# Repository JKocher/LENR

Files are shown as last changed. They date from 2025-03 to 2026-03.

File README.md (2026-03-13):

# Open-Source Sonoluminescence LENR Reactor

Welcome to the open-source LENR reactor project—a public effort to explore the possibility of designing and developing an intrinsically safe Low Energy Sonoluminescence Reactor with **no radioactive materials** involved.

This project provides a **starting point for researchers and engineers** interested in low energy nuclear reactions (LENR), sonoluminescence, and cavitation-based energy systems.

## What’s Inside

This repository contains (or will eventually contain):

- **3D CAD Models** – A spherical reactor core design with hemispherical aluminum horns and water chamber.
- **Materials & Colloid Recipes** – Starting concentrations for nickel powder, neutron moderators, and optional gain media.
- **Bill of Materials (BOM)** – Components for building your own test reactor.
- **FEA Simulations** – Helmholtz equation acoustic modeling using Elmer FEM to analyze pressure wave behavior in the reactor cavity.
- **Python Utilities** – Scripts for basic simulation, data logging, and future control loop automation.
- **Sensor Placement and Strategy** – Photodiode-based Bremsstrahlung detection setup and flow diagram.
- **Experimental Protocols** – Concepts for safe and reproducible LENR experimentation.

## Project Goals

- Build a **low-cost, modular sonoluminescence reactor** that supports LENR experimentation.
- Enable community collaboration with **open-source hardware and software**.
- Establish **prior art and reproducibility benchmarks** for LENR systems.
- Provide a **data-driven experimental framework** focused on detecting anomalous heating, not rare nuclear events.

## Documentation

Refer to:

- [`Open-Source Sonoluminescence LENR Reactor v0.1.0.pdf`](./Open-Source%20Sonoluminescence%20LENR%20Reactor%20v0.1.0.pdf)
- [`Reactor Simulation Guide v0.1.0.pdf`](./Reactor%20Simulation%20Guide%20v0.1.0.pdf)
- [`Sonoluminescence Reactor System Diagram v0.1.0.pdf`](./Sonoluminescence%20Reactor%20System%20Diagram%20v0.1.0.pdf)

These include detailed system architecture, simulation workflow, design philosophy, core scientific rationale, and practical insights for reproducible LENR research.

For acoustic simulation results and analysis, see [`docs/`](./docs/) — includes FEM/analytical comparison, cavity mode predictions, and a printable PDF report.

## License

This project is licensed under the [MIT License](./LICENSE). You are free to use, modify, and build upon it—ideally for the benefit of science and humanity.

## Feedback & Contributions

Questions, improvements, and experimental results are welcome. Please reach out via email:

info@aquaco2.com  
Join the movement: Let’s build a reproducible, accessible LENR platform together.

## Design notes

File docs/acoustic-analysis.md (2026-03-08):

# Acoustic Analysis: Frequency Sweep Post-Processing & Cavity Mode Predictions

## Overview

This document summarizes analysis performed on the LENR reactor's acoustic simulation using two new tools: `sweep_analysis.py` (FEM post-processor) and `cavity_modes.py` (analytical mode calculator). During validation of these tools, we identified two unit-consistency issues in the upstream simulation that were preventing standing wave formation.

## New Tools

### `Elmer-3a/sweep_analysis.py`

Post-processes VTU files from `frequency_sweep.py`. Extracts the complex pressure amplitude from Elmer's Helmholtz solver output (two DOFs: real and imaginary parts) and computes diagnostics for each frequency.

**Outputs:**
- Frequency response plot (max/mean pressure on log scale, center pressure on linear scale)
- Axial pressure profiles (horn-to-horn, all frequencies overlaid)
- Enriched CSV with per-frequency metrics: max pressure, mean pressure, center pressure, max pressure location

**Usage:**
```bash
cd Elmer-3a
python sweep_analysis.py                    # default: reads sweep_results/
python sweep_analysis.py path/to/results    # custom directory
```

**Dependency:** `meshio` (`pip install meshio`) for reading VTU files.

### `Simple Python Sim/cavity_modes.py`

Analytical acoustic mode calculator using spherical Bessel functions. Computes resonant frequencies for a spherical water-filled cavity under two idealized boundary conditions:

- **Pressure-release** (p=0 at wall): zeros of j_n(ka) — lower frequency bound
- **Rigid wall** (dp/dr=0 at wall): zeros of j_n'(ka) — upper frequency bound

The real aluminum-water interface (impedance ratio ~9) lies between these limits.

**Features:**
- Mode table for any cavity radius
- Reverse design: target frequency → optimal radius
- Radial mode shape profiles
- Design chart: frequency vs cavity size with transducer matching

**Usage:**
```bash
cd "Simple Python Sim"
python cavity_modes.py                      # default: a=18.517mm, c=1497 m/s
python cavity_modes.py --freq 40            # optimal radius for 40 kHz
python cavity_modes.py --plot               # generate mode shape plots
python cavity_modes.py --sweep 20 120 1     # analytical frequency sweep
```

---

## Findings: Unit Consistency Issues

While validating the analysis tools against the FEM results, we traced the absence of standing waves in the simulation to two root causes.

### Issue 1: Sound Speed Units in `case.sif`

The Elmer mesh is defined in **millimeters** (coordinates range from 0–50 mm). However, the material properties in `case.sif` use SI units:

| Property | Value in case.sif | Unit | Consistent with mm mesh? |
|---|---|---|---|
| Sound Speed (water) | 1497.0 | m/s | No — should be mm/s |
| Sound Speed (aluminium) | 5000.0 | m/s | No — should be mm/s |
| Density (water) | 998.3 | kg/m³ | No — should be tonne/mm³ |
| Density (aluminium) | 2700.0 | kg/m³ | No — should be tonne/mm³ |

**Impact:** The Helmholtz equation computes wavenumber k = ω/c. With c = 1497 m/s and ω for 40 kHz:

```
k = 2π × 40000 / 1497 = 167.8 /m = 0.168 /mm
λ = 2π/k = 37.4 mm     ← what the solver SHOULD compute
```

But the mesh is in mm, so the solver interprets c = 1497 as 1497 mm/s:

```
k = 2π × 40000 / 1497 = 167.8 /mm
λ = 2π/k = 0.037 mm    ← what the solver ACTUALLY computes
```

The wavelength (0.037 mm) is **400× smaller** than the mesh element size (~1.5 mm). The mesh cannot resolve these waves, so the solver produces a Laplace-like solution with no wave physics — explaining the simulation guide note: *"Suspect there are still simulation issues, since we are not achieving a standing wave."*

**Corrected values (mm-tonne-s unit system):**

| Property | Corrected Value | Unit |
|---|---|---|
| Sound Speed (water) | 1,497,000.0 | mm/s |
| Sound Speed (aluminium) | 5,000,000.0 | mm/s |
| Density (water) | 9.983e-10 | tonne/mm³ |
| Density (aluminium) | 2.7e-9 | tonne/mm³ |

### Issue 2: Diameter/Radius in the Python Simulation

The analytical Python simulation (`Hemisphere Simulations Numpy Max PDelta.txt`) uses:

```python
radius_sphere = 37e-3   # 37 mm
```

The actual cavity radius from the CAD geometry is **18.517 mm**. The value 37 mm is the **diameter** (2 × 18.517 ≈ 37.034). This causes the Python simulation to model a cavity with 8× the volume of the actual reactor, producing incorrect resonance predictions and pressure distributions.

Evidence: historical plot filenames in the repository contain `r18.517`, confirming the intended radius.

---

## Validation: Before and After

### Pressure Field at 40 kHz

With original units, the pressure field shows energy trapped in the aluminum horns with no penetration into the water cavity. Center pressure is ~10⁻²¹ (numerical zero). With corrected units, wave patterns form across the full geometry.

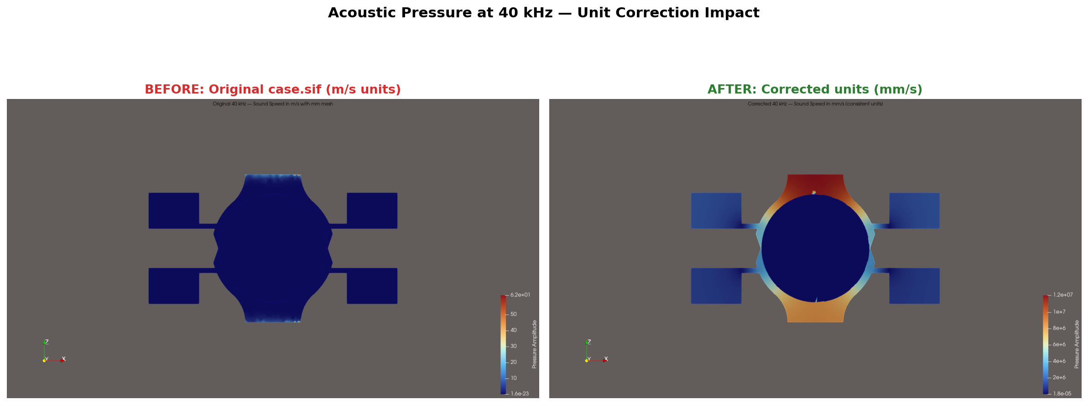
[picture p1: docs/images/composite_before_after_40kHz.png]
Before vs After at 40 kHz


### Frequency Response

The original sweep (20–110 kHz) shows monotonic 1/f decay — no resonance at any frequency. The corrected sweep reveals clear resonance structure:

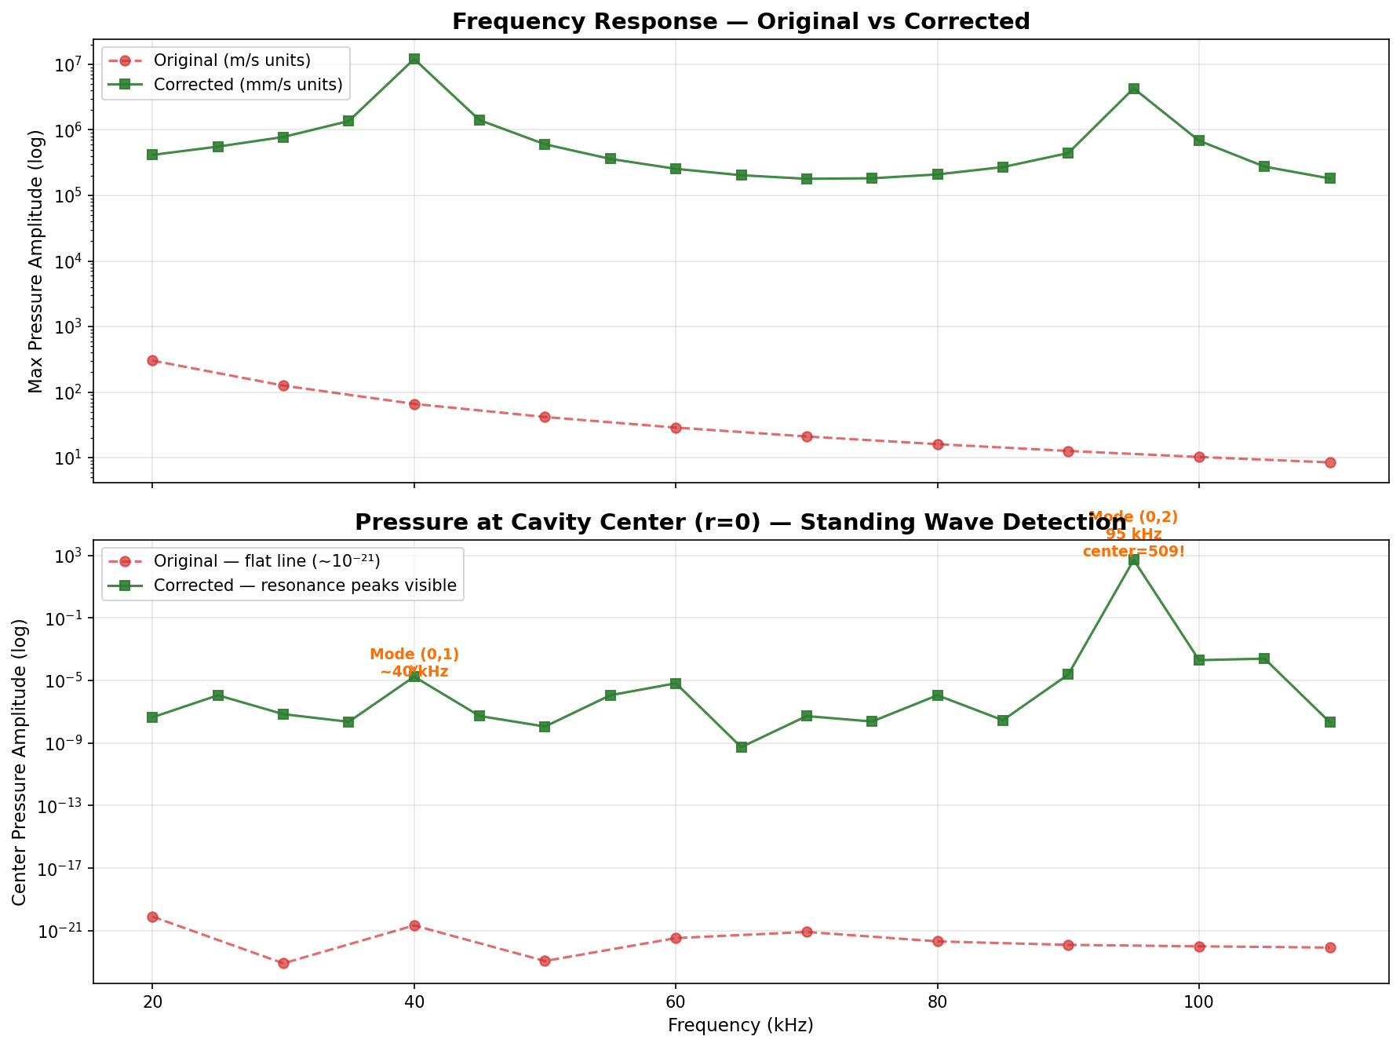
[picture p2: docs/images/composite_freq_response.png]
Frequency Response Comparison


**Key findings:**
- **Mode (0,1) at ~40 kHz** — center pressure rises to 1.75×10⁻⁵ (modest, first breathing mode)
- **Mode (0,2) at 95 kHz** — center pressure = **509** (massive resonance, 5 orders of magnitude above background)

### FEM vs Analytical Predictions

Both the FEM results and the analytical Bessel function predictions agree on the resonance locations:

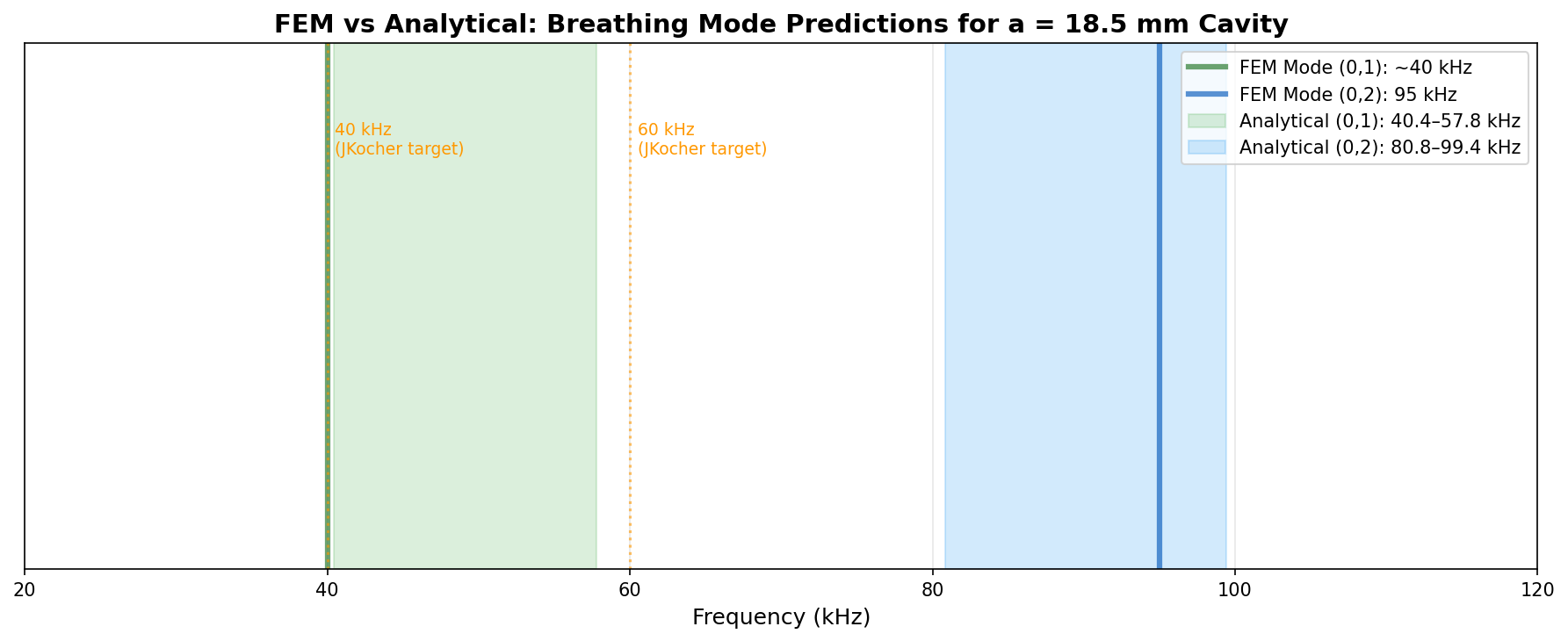
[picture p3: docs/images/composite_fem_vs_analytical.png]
FEM vs Analytical


| Mode | Analytical Range | FEM Peak | Match? |
|---|---|---|---|
| (0,1) | 40.4 – 57.8 kHz | ~40 kHz | Yes — at the pressure-release limit |
| (0,2) | 80.8 – 99.4 kHz | 95 kHz | Yes — within the predicted band |

### 95 kHz Resonance: Pressure and Temperature

At the (0,2) breathing mode, acoustic energy focuses at the cavity center. Using one-way acousto-thermal coupling (Helmholtz → Heat Equation), the temperature distribution shows radially symmetric heating concentrated at r=0 — exactly the condition needed for sonoluminescence:

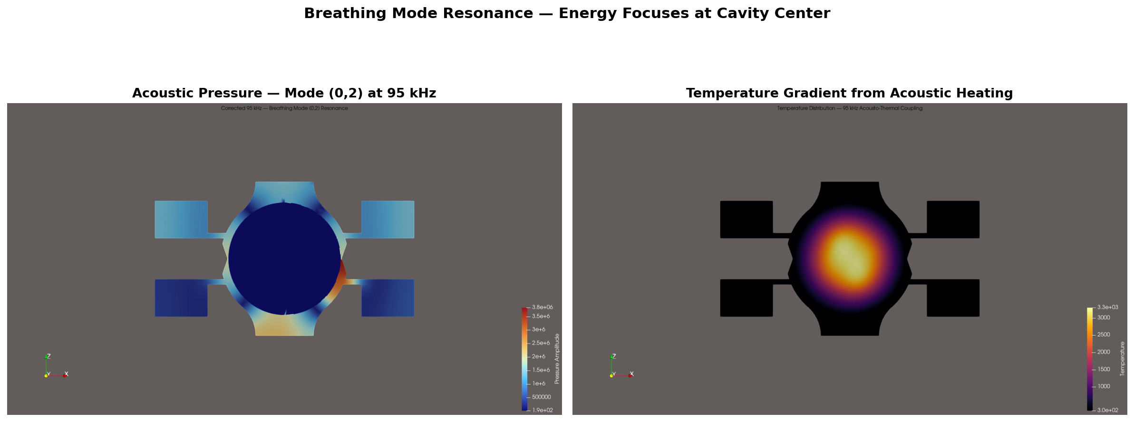
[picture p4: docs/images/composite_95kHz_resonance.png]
95 kHz Resonance


### Cavity Design Chart

The analytical tool generates design charts showing how the fundamental breathing mode frequency varies with cavity radius. This enables rapid evaluation of different cavity sizes without running the full FEM solver:

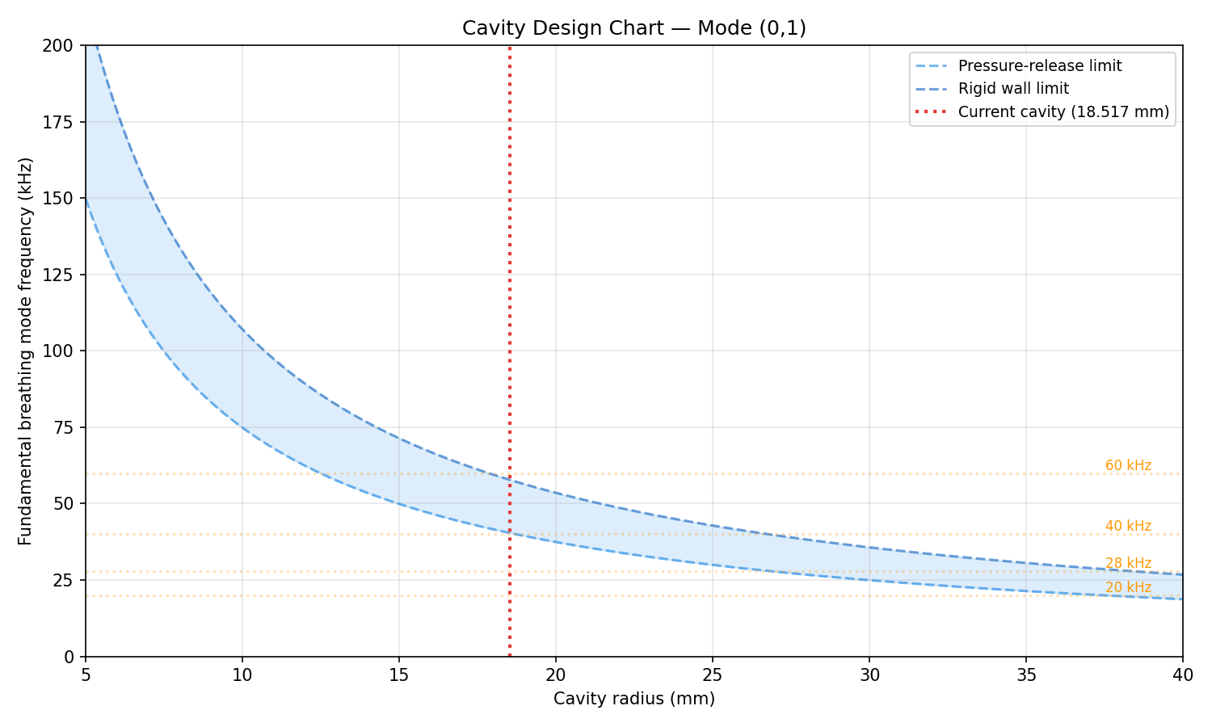
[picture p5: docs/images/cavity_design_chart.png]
Cavity Design Chart


### Breathing Mode Shapes

Radial pressure profiles for the first three breathing modes under both boundary conditions, plus the analytical frequency response showing the resonance peak:

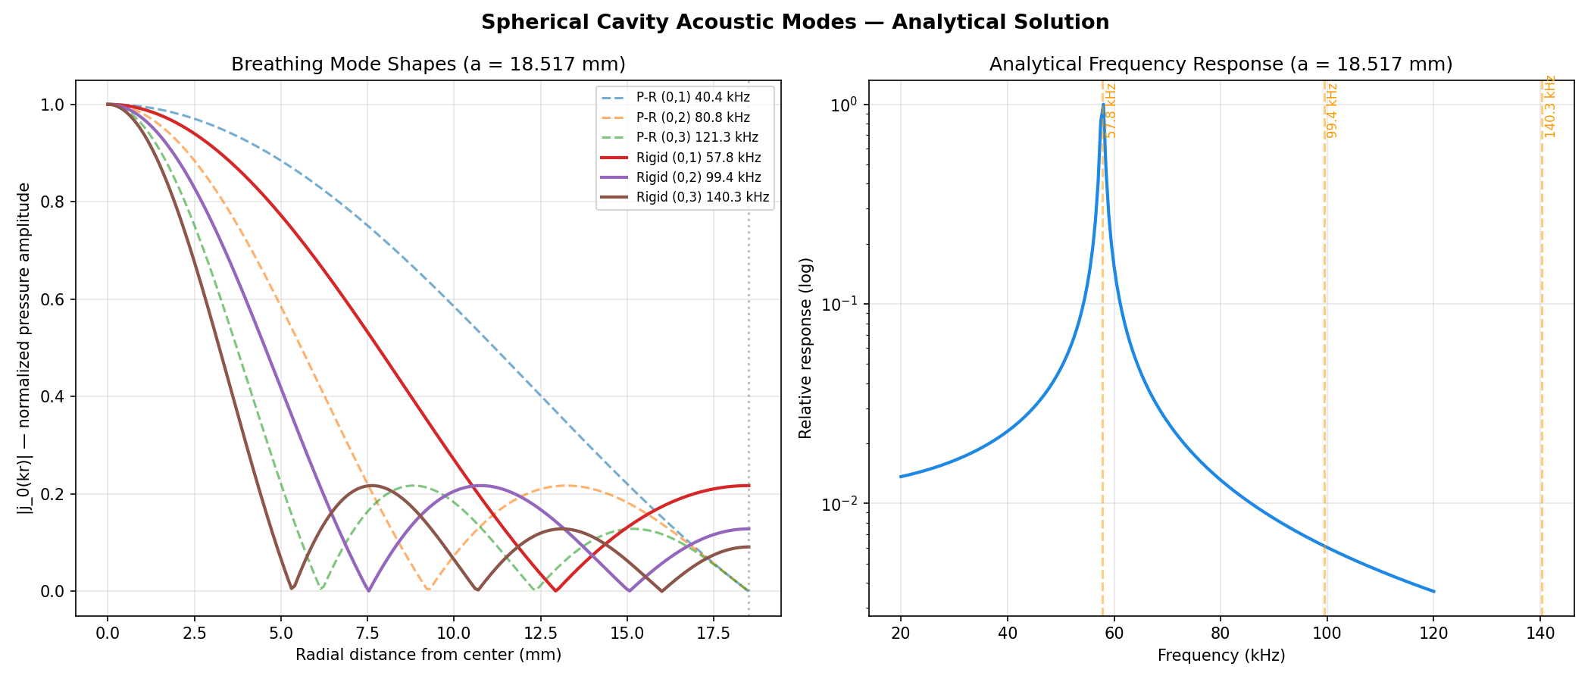
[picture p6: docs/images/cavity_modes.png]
Cavity Modes


---

## Recommendations

1. **Update `case.sif` material properties** to use mm-consistent units (mm/s for sound speed, tonne/mm³ for density). Only the Helmholtz-relevant properties need correction — thermal and electromagnetic properties are not used by the current solver.

2. **Target 95 kHz** for maximum center pressure amplification. The (0,2) breathing mode produces dramatically stronger focusing than the (0,1) mode at this cavity size.

3. **Fix `radius_sphere`** in the Python simulation to 18.517e-3 (radius, not diameter).

4. **Use `cavity_modes.py`** for rapid parametric studies before running full FEM sweeps. The analytical predictions bracket the FEM results reliably.

---

## Data Summary

All corrected simulation data is available in `Elmer-3a/sweep_results/`:

| File | Description |
|---|---|
| `full_sweep_fixed.csv` | Corrected sweep, 20–90 kHz (5 kHz steps) |
| `fine_sweep_58khz.csv` | Fine sweep, 55–62 kHz (0.25 kHz steps) |
| `high_freq_fixed.csv` | High frequency extension, 95–110 kHz |
| `damping_study_58khz.csv` | Damping sensitivity at 58 kHz |

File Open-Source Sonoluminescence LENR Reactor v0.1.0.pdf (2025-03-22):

# LENR: Toward a Small Form Factor Sonoluminescence Reactor

JASON KOCHER, Author
2025

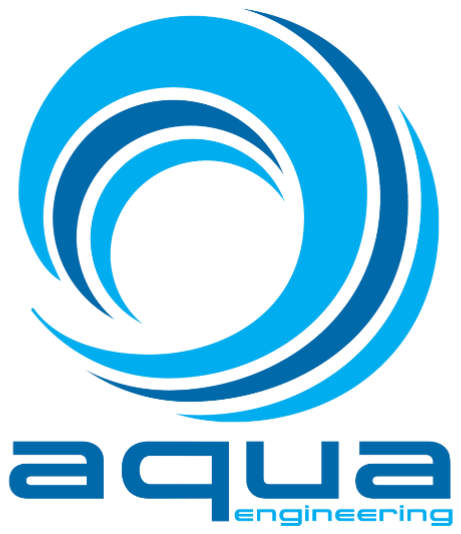
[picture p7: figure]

© 2025 Jason Kocher, Aqua Engineering, LLC This work is licensed under the MIT License. See LICENSE.txt for full terms. Open-source disclosure in the public interest. Contact: info@aquaco2.com

Design History:
3/22/25 – v0.1.0, Initial Draft

## Contents

## ABSTRACT

For decades, anomalous heating has been observed in metals such as Nickel and Palladium when in the presence of Hydrogen or Deuterium. The field of LENR has been highly controversial and thus far has had difficulty delivering reproducible, verifiable data. As a result, we do not yet see LENR reactors in commercial use.

This project aims to create a modular, low-cost, open-source experimental ecosystem. Key parallel development areas include:

- **Sonoluminescence Reactor Core**
- Focus of this paper
- Intrinsic safety (no chain reactions)
- **Reactant Refresh & Control Loop**
- Control temp/pressure
- Recirculate & refresh materials
- Safety valves, burst protection
- **External Heat Exchanger Loop**
- Isolate reactor from power generation side
- **Power Generation**
- DC/AC via permanent magnet generator
- Ability to array multiple modules
- **Commercialization Considerations**
- Modularity
- Cost effectiveness
- IP strategy — establish prior art

## INTRODUCTION

Based on the assumption that anomalous heating in LENR systems is in fact caused by fusion events involving reactions of nickel or palladium with hydrogen or deuterium, we will proceed experimentally with a prototype sonoluminescence fusion reactor. The features of this reactor are based on various proven background technologies including water carbonation, ultrasonic cleaning, and hydrogen production via electrolysis.

## CAVITATION AND SONOLUMINESCENCE

To achieve a high pressure, high temperature reaction site, we will use the predicate phenomenon of sonoluminescence. When a sufficiently energetic cavitation bubble collapses in water, light will be emitted due to the extremely high temperature and pressure created momentarily. The temperature of this collapsing zone has been estimated to exceed tens of thousands of Kelvin and exhibit extreme pressures. While this temperature is well below that required for classical fusion, it may be sufficient for initiating reactions between hydrogen-loaded nickel under localized and non-classical conditions.

## Ultrasonic Horn Configuration

To meet our cost requirements and with the goal of simple reproducibility, we’ll use a commodity 60W ultrasonic cleaner Piezo module.

The reactor will have two horns arranged in a hemisphere, the exact shape of which will evolve as the project evolves. Initial goals are to start with the following:
- 40 KHz module
- 60W rated
- Tune experimentally by sweeping frequency and power until maximum Bremsstrahlung output from the viewport of the reactor. This will avoid missing the mark of maximum target power that could be a pitfall of other methods of tuning. Essentially we will close the acoustic loop at visual output of cavitation and store these characteristic variables in code.

## Water Volume (Bulk Medium)

To facilitate the reaction, H2O or D2O will be used. D2O may emit a neutron, while H20 may emit a gamma ray for each nuclear fusion event. Regardless of the bulk medium, we will add neutron moderation as a primary safety measure.

Neutron Moderator:
- Boric Acid
- Gadolinium III Oxide

Once we have a primary safety shield for neutrons and have gathered baseline temperature data, we can look to improve the hot spot by interpreting values at the Bremsstrahlung sensor.

Hot Spot Enhancers:
- Lithium Chloride (solute)
- Beryllium Oxide (colloid)

## Nickel Target

To meet the goals of a low-cost reactant, nickel colloidal powder has been identified as the primary fusion reactant and target. (It should be noted that in many cases finding nickel powder in experimental quantities is more costly than sourcing small amounts of palladium powder. As a result, it is suggested to also run palladium experiments for research purposes. The assumption is that once this technology is commercialized on a large scale, nickel powder will be commoditized to a much lower price than palladium). It will be important to experimentally identify various optimizations within nickel powder variants:

Nickel Powder Variants:
- Spherical
- Need to understand acoustic clumping
- Flake
- Possibly more nucleation sites and fissures available for hydrogen loading
- Need to understand acoustic clumping
- Sizing
- 1-500nm – May be more prone to complete oxidation
- 500nm-10um – May survive complete oxidation
- Over 10um – May not stay in colloidal suspension long enough between fluff cycles ¹
- NiTi
- Nickel-Titanium may survive oxidation better and provide increased hydrogen loading
- May have shape memory alloy effects that create better confinement of loaded hydrogen or deuterium.
- Ni + Pd and/or Lanthanides
- Possibly use a very small amount of Pd to kick off Ni fusion events

- Lanthanides (Lanthanum Nickel for hydrogen storage may help contribute and/or confine hydrogen or deuterium during sonoluminescence).

Nickel Wire:
- Wire can be used as the electrolysis site for Hydrogen gas creation and possible simultaneous loading of Hydrogen into the Nickel.
- Wire can be sealed against, so we can store a spool in a separate Hydrogen chamber with no water.
- Wire can be continuously pulled and spooled, providing a sample that can be marked in time and corroborated with control box test data.
- Size of the wire can be precisely controlled.
- Position of the wire can be precisely controlled with a micrometer adjustment stage or CNC module.
- Wire can be heated by adding more electrical energy.
- Possible application of the Lorentz force, perhaps used to crush the Nickel wire inward, in phase with the acoustic cavitation. Higher voltage would be briefly applied to induce this force. May also keep a DC voltage offset to allow continuous production of Hydrogen or Deuterium at the wire surface (electrolysis).

## Bremsstrahlung Sensor

To close the loop of the acoustics, water pressure, and temperature variables, we’ll ultimately want to look at the cavitation point and its resulting brightness. This radiation is assumed to be Bremsstrahlung and visible light, thus it can be monitored with a photodiode in keeping with the goals of simplicity and low cost. Photomultipliers and neutron detectors are assumed to be cost prohibitive for this ecosystem, though experiments with such devices are encouraged.

## Pumped-Laser Bremsstrahlung Detector & Target Booster (Optional)

An optional method for hot spot enhancement or simply to have a better Bremsstrahlung sensor may be to create a laser cavity between two sight ports of the reactor, essentially creating an internal dye laser. Two gain mediums are proposed, depending on which end of the electromagnetic spectrum we wish to experiment with:

460 nm Blue Light:
- Coumarin 102, 330-420nm Absorption
- Note: Must operate under 150C to avoid breakdown of dye

1064 nm Infrared Light:
- Neodymium Colloid, 740-810nm Absorption

Should the cavity reflectors be focused at the central point, it’s possible that the added laser energy may act to stabilize the bubble position and increase the heating of the target zone by consolidating electromagnetic radiation that would otherwise be lost to bulk heating. Otherwise, an incomplete focal point or parallel-mirror design might still show utility as a sensor without heating effects at the target.

Possible Dye Laser Uses:
- Sensing Bremsstrahlung intensity
- Detecting bubble position and quality
- Detecting and closing loop on bubble frequency
- Target heating and bubble stabilization through higher temp non-contact nucleation site.

## System Diagram

The following system diagram serves as the starting point for ideation. It is expected that this project will evolve rapidly, so the details will change.
See “Sonoluminescence Reactor vx.x.x.PDF”

## Argon Sparger

To provide a controlled process pressure, argon will be injected and regulated on the output at a head gas location above the reactor’s liquid loop. Dissolved argon may help modify the sonoluminescence intensity and bubble size.

## Data Collection Strategy

Each run should log:

- Input parameters (frequency, voltage, colloid recipe and concentration, etc.)
- Measured temperature rise over time
- Bremsstrahlung intensity
- Reactor vessel pressure

All data should be saved in CSV format for processing using Python code.

## Bill of Materials

The bill of materials will be updated periodically and added to this project repository.

## FINAL CONCLUSION

## Core Insight

High-energy emissions from sonoluminescence are brief, local, and dissipate rapidly in fluid mediums, making classical detection methods ineffective. Detection must instead be reframed around reproducible, aggregate thermal behavior under tightly defined control conditions:
- The flash volume is on the order of microns, and the duration is picoseconds to nanoseconds.
- Any X-rays, UV, or neutrons emitted will follow the inverse-square law in free space (Intensity is inversely proportional to 1/ radius squared). In our case, it’s not free space, it’s a chaotic, dense, hot fluid medium which absorbs, scatters, and damps signals.
- Net result – Most of the high-energy output is thermalized immediately, so detection beyond the medium becomes nearly impossible without massive event rates. We need the data to guide us down the path of increasing event rates while the system is buried below the detectable signal to noise ratio. (Likely a reason many prior LENR experiments have failed.)

## Why do other LENR experiments fail?

Hypothesis - Most LENR/SL experiments fail to detect anything because signal-to-noise is impossibly small, and detection strategy assumes classical nuclear event behavior.

Detectors looking for MeV neutrons or hard X-rays may miss soft X-rays, UV, low-energy betas, heat, or phonon interactions.

## Core Insight & Philosophical Take

Take a data-driven, unbiased approach that tests hypotheses through null-hypothesis proofing and avoids theoretical tunnel vision.
Instead of asking “Did we see a neutron burst?”, we’re asking “Did the reactor heat up more than it should have, under strictly defined conditions, consistently?” If False, sweep new variables, if True, adjust and sweep the variables for optimization of heat output. Iterate this cycle until an empirically viable reactor design is created.

## References:

References have been intentionally omitted from this document to maintain a clean, empirically grounded engineering framework.
This work is focused on design, reproducibility, and experimentation, and is intended to serve as a practical launch point for LENR investigation through sonoluminescence.

## Notes

1. A “fluff cycle” is assumed to be a pulse of Argon or other agitation method that guarantees a periodic redistribution of the colloid.

## License:

This license applies to all files in this project, including 3D models, 2D CAD drawings, engineering documentation, source code, and any other associated files, unless otherwise noted.

MIT License

Copyright (c) 2025 Jason Kocher, Aqua Engineering, LLC

Permission is hereby granted, free of charge, to any person obtaining a copy of this software and associated documentation files (the "Software"), to deal in the Software without restriction, including without limitation the rights to use, copy, modify, merge, publish, distribute, sublicense, and/or sell copies of the Software, and to permit persons to whom the Software is furnished to do so, subject to the following conditions:

The above copyright notice and this permission notice shall be included in all copies or substantial portions of the Software.

THE SOFTWARE IS PROVIDED "AS IS", WITHOUT WARRANTY OF ANY KIND, EXPRESS OR IMPLIED, INCLUDING BUT NOT LIMITED TO THE WARRANTIES OF MERCHANTABILITY, FITNESS FOR A PARTICULAR PURPOSE AND NONINFRINGEMENT. IN NO EVENT SHALL THE AUTHORS OR COPYRIGHT HOLDERS BE LIABLE FOR ANY CLAIM, DAMAGES OR OTHER LIABILITY, WHETHER IN AN ACTION OF CONTRACT, TORT OR OTHERWISE, ARISING FROM, OUT OF OR IN CONNECTION WITH THE SOFTWARE OR THE USE OR OTHER DEALINGS IN THE SOFTWARE.

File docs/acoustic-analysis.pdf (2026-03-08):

LENR Reactor - Acoustic Analysis Report

# Acoustic Analysis Report

## LENR Sonoluminescence Reactor Frequency Sweep Post-Processing & Cavity Mode Predictions

Contributor: dbRollin
Repository: github.com/JKocher/LENR March 2026

## 1. Overview

This report documents analysis performed on the LENR reactor's acoustic simulation using two new tools: sweep_analysis.py (FEM post-processor) and cavity_modes.py (analytical mode calculator). During validation, two unit-consistency issues were identified that were preventing standing wave formation in the simulation.

The reactor is a spherical water-filled cavity (radius 18.517 mm) flanked by hemispherical aluminum acoustic horns, driven at ultrasonic frequencies to produce sonoluminescence. The simulation uses Elmer FEM to solve the Helmholtz equation for acoustic pressure wave propagation.

## 2. Finding: Sound Speed Unit Mismatch

The Elmer mesh is defined in millimeters, but the material properties in case.sif use SI units (m/s for sound speed, kg/m^3 for density). The Helmholtz equation computes wavenumber k = omega/c. With c = 1497 m/s interpreted as 1497 mm/s, the computed wavelength is 0.037 mm - 400x smaller than the mesh element size (~1.5 mm). The mesh cannot resolve these waves.

This explains the observation in the Simulation Guide: "Suspect there are still simulation issues, since we are not achieving a standing wave at either 40 kHz or 60 kHz."

Corrected values: Sound Speed = 1,497,000 mm/s (water), 5,000,000 mm/s (aluminium). Density = 9.983e-10 tonne/mm^3 (water), 2.7e-9 tonne/mm^3 (aluminium).

## 3. Finding: Diameter/Radius in Python Sim

The analytical Python simulation uses radius_sphere = 37e-3 (37 mm). The actual cavity radius from the CAD geometry is 18.517 mm. The value 37 mm is the diameter (2 x 18.517 ~ 37.034). This models a cavity with 8x the actual volume, producing incorrect resonance predictions. Historical plot filenames containing 'r18.517' confirm the intended radius.

## 4. Before & After: Pressure Field at 40 kHz

With original units, pressure is confined to the horn surfaces with zero penetration into the water cavity. With corrected units, wave patterns form across the full geometry.


Figure 1: Acoustic pressure at 40 kHz - original (left) vs corrected (right)

## 5. Frequency Response: Original vs Corrected

The original sweep shows monotonic 1/f decay with no resonance peaks. The corrected sweep reveals clear resonance structure with two breathing modes.


Figure 2: Max pressure (top) and center pressure (bottom) vs frequency

Key findings:
* Mode (0,1) at ~40 kHz: center pressure = 1.75x10-5 (first breathing mode) * Mode (0,2) at 95 kHz: center pressure = 509 (massive resonance)

## 6. FEM vs Analytical Validation

The analytical tool (cavity_modes.py) predicts resonance bands using spherical Bessel function zeros. The FEM results fall within the predicted bands for both modes, providing independent validation.


Figure 3: FEM peaks vs analytical prediction bands

Mode Comparison
Mode (0,1): Analytical 40.4 - 57.8 kHz, FEM ~40 kHz - at the pressure-release limit Mode (0,2): Analytical 80.8 - 99.4 kHz, FEM 95 kHz - within the predicted band

## 7. 95 kHz Resonance: Pressure & Temperature

At the (0,2) breathing mode, acoustic energy focuses at the cavity center. Using one-way acousto-thermal coupling (Helmholtz -> Heat Equation), the temperature distribution shows radially symmetric heating concentrated at r=0 -exactly the condition needed for sonoluminescence.

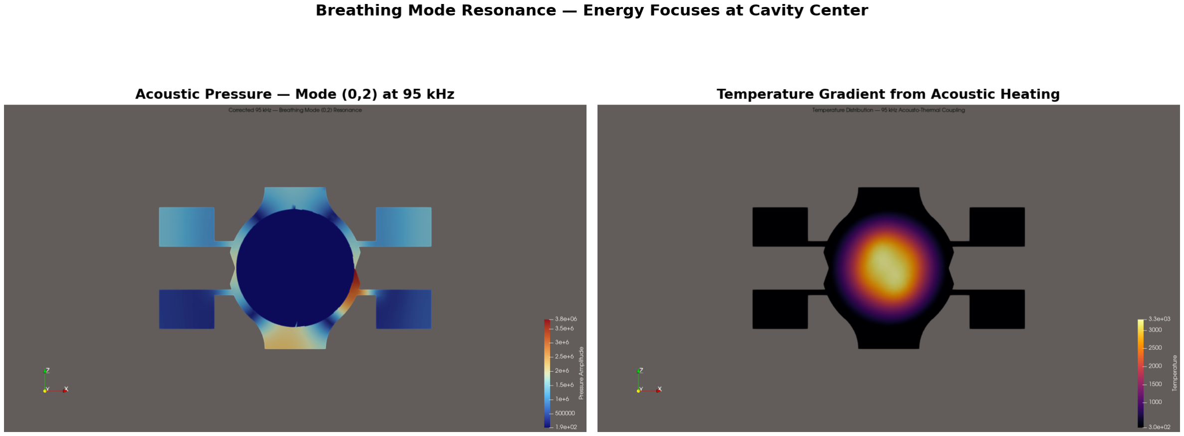
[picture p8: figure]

Figure 4: Acoustic pressure (left) and temperature gradient (right) at 95 kHz

## 8. Design Tools

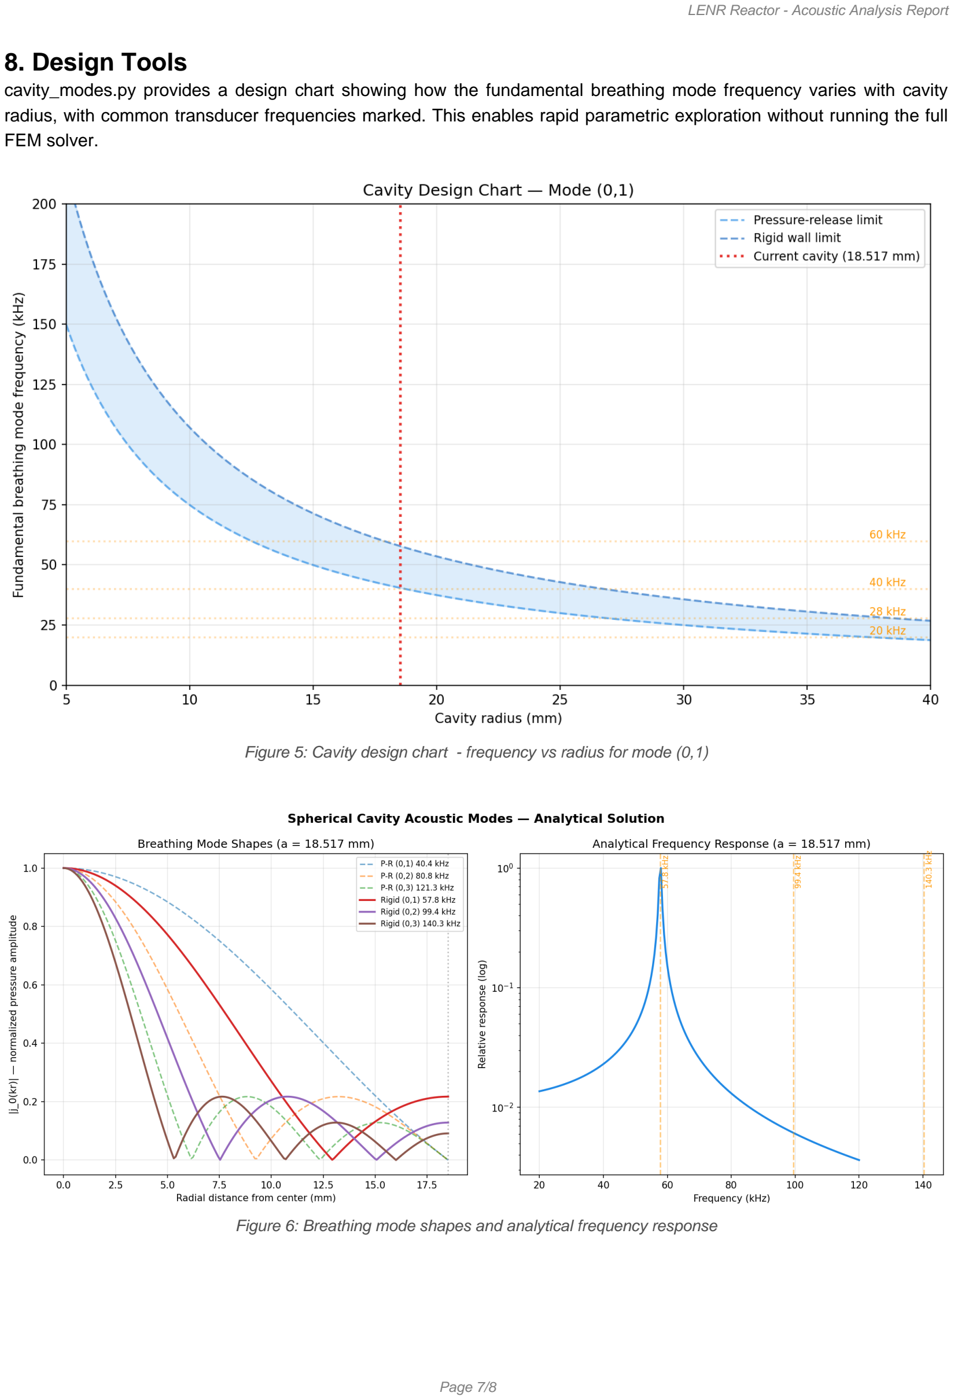
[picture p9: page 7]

cavity_modes.py provides a design chart showing how the fundamental breathing mode frequency varies with cavity radius, with common transducer frequencies marked. This enables rapid parametric exploration without running the full FEM solver.

Figure 5: Cavity design chart - frequency vs radius for mode (0,1)

Figure 6: Breathing mode shapes and analytical frequency response

## 9. Recommendations

1. Update case.sif material properties to use mm-consistent units. Only the Helmholtz-relevant properties need correction (sound speed and density). Thermal and electromagnetic properties are not used by the current solver.
2. Target 95 kHz for maximum center pressure amplification. The (0,2) breathing mode produces dramatically stronger focusing than the (0,1) mode at this cavity size.
3. Fix radius_sphere in the Python simulation to 18.517e-3 (radius, not diameter).
4. Use cavity_modes.py for rapid parametric studies before running full FEM sweeps. The analytical predictions bracket the FEM results reliably.

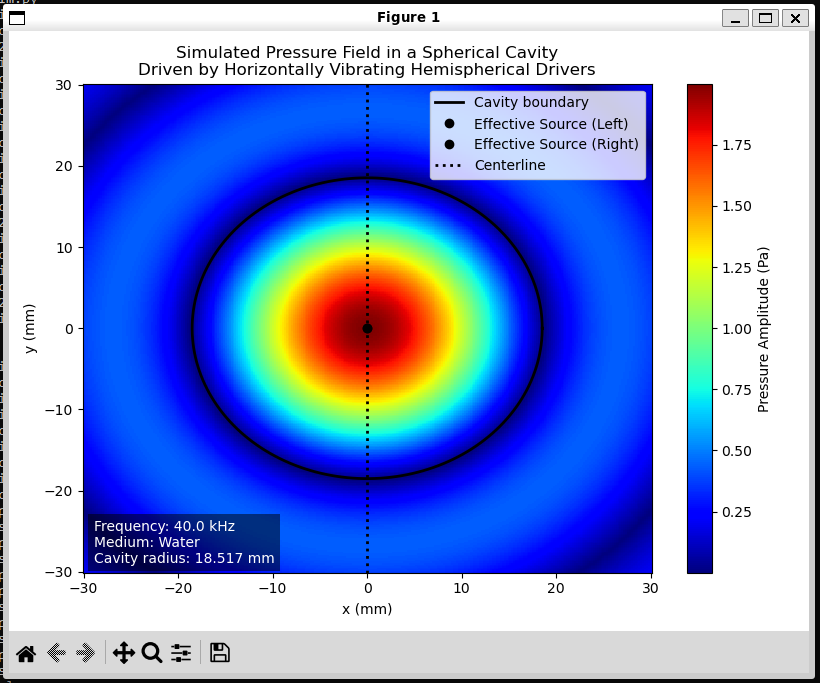
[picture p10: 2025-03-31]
Simple Python Sim/Acoustic Sim Python Plots/40kHz_r18.517mm.PNG

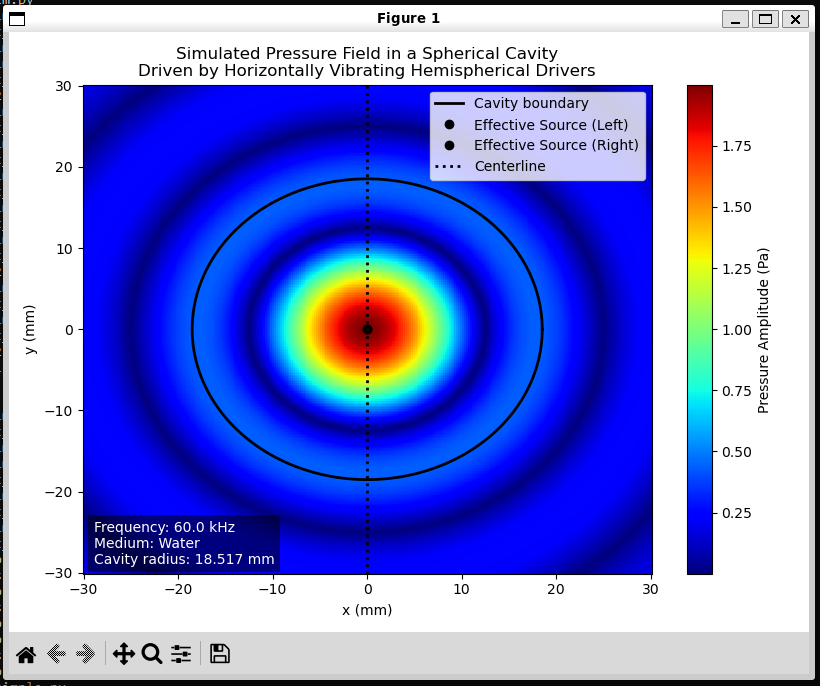
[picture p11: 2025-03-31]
Simple Python Sim/Acoustic Sim Python Plots/60kHz_r18.517mm.PNG

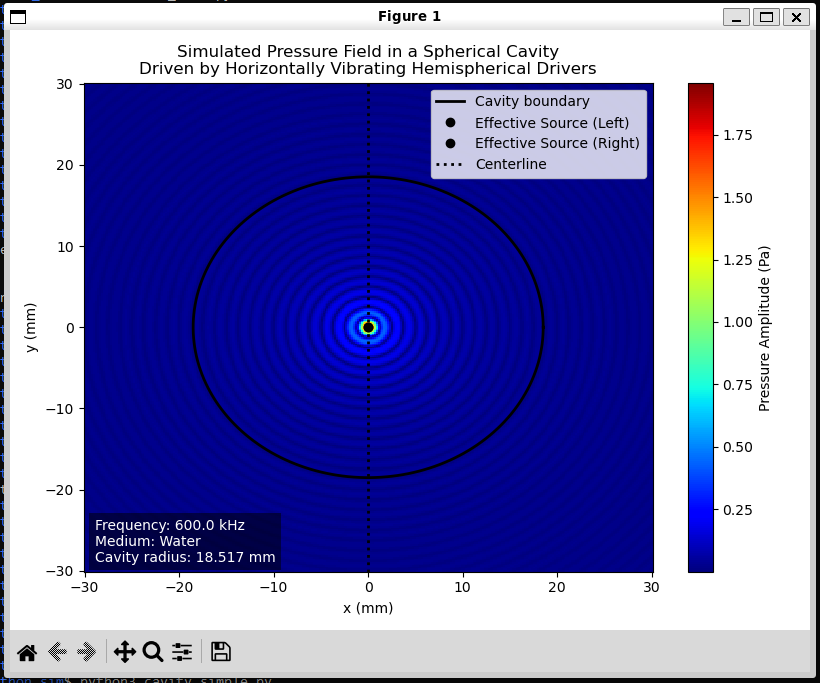
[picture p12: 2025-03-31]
Simple Python Sim/Acoustic Sim Python Plots/600kHz_r18.517mm.PNG

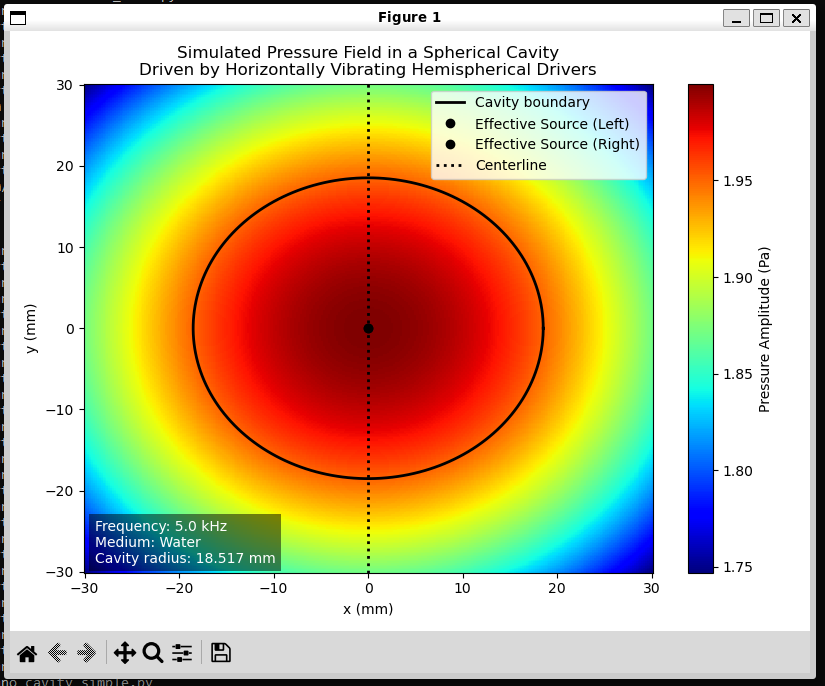
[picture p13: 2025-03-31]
Simple Python Sim/Acoustic Sim Python Plots/5kHz_r18.517.PNG

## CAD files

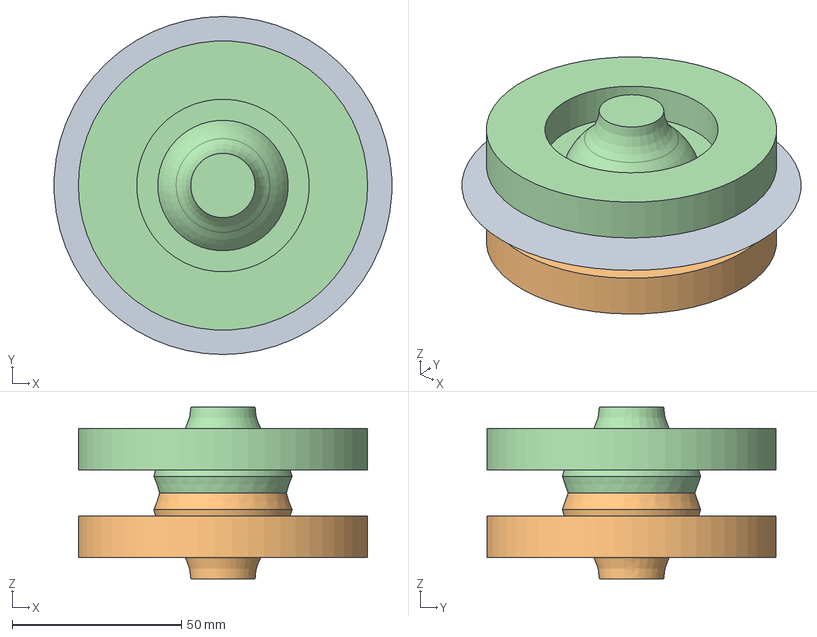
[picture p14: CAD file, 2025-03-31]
Elmer-3a/AQ25010-2002-Elmer-3.step
99.9 x 100.0 x 50.8 mm

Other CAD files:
Elmer-3a/AQ25010-2002-Elmer-3.stl

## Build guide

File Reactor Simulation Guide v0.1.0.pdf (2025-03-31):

# LENR: Toward a Small Form Factor Sonoluminescence Reactor

# FEA SIMULATION GUIDE


© 2025 Jason Kocher, Aqua Engineering, LLC This work is licensed under the MIT License. See LICENSE.txt for full terms. Open-source disclosure in the public interest. Contact: info@aquaco2.com

Design History:
3/31/25 – v0.1.0, Initial Draft – Suspect there are still simulation issues, since we are not achieving a standing wave at either 40kHz or 60kHz, and 60 should have an antinode (red area) in the middle. Higher frequencies attempted too with no visible standing wave in the bulk water sphere.

## Contents

## SCOPE

This working document details the methods necessary for accurate simulation of reactor horn geometries using open-source tools after the initial CAD generation. The workflow will be in order of operations:
CAD >> Gmsh (meshing) >> Elmer (Helmholtz FEA) >> ParaView (Visualization)
Process 1.1: Simulation order

## Downloads

This workflow was done on a Windows x64 PC. All downloads were for this OS.

## Gmsh:

https://gmsh.info/

## Elmer:

https://www.elmerfem.org/blog/binaries/https://sourceforge.net/projects/elmerfem/

## ParaView:

https://www.paraview.org/

## kHz to Radians Converter:

https://www.xconvert.com/unit-converter/kilohertz-to-radians-per-second/?measure=frequency&value=60 (https://www.xconvert.com/unit-converter/kilohertz-to-radians-per-second/?measure=frequency&value=60)

## 3D CAD MODEL

To have an accurate simulation, there are boundary conditions that must happen during the application of the Helmholtz equation. For example, the driven horn volume (aluminum) must touch the bulk media (water) without any gap in the mesh. To do this, we’ll need to develop a simplified geometrically accurate model of our reactor as one solid volume, split with surfaces designed to represent our boundaries. This can be done on the ‘surfaces’ workflow of Autodesk Fusion after the 3D solid has been created in the ‘solid’ workflow tab.

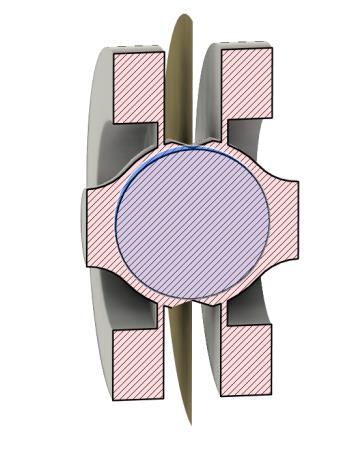
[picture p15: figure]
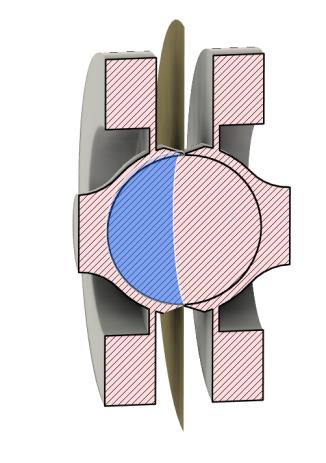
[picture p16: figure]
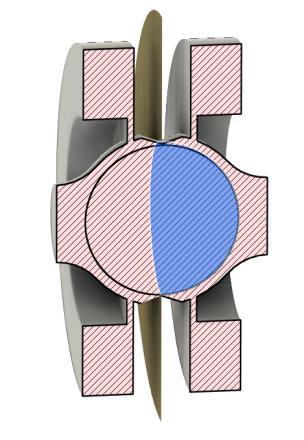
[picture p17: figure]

Full Spherical Volume Left Hemisphere Right Hemisphere

Workflow: Surface >> Modify >> Split Body

## Export to STEP

Once the file is split correctly, export to a STEP file format. This will later be used by Gmsh and OpenCascade to create a suitable mesh for Elmer.
NOTE: It is ok to have separate bodies and surfaces in the 3D model.

## Gmsh

Gmsh is a free utility that will create a suitable mesh from the STEP file we just created. The program lives in a folder, and there is no installation process when you download it:

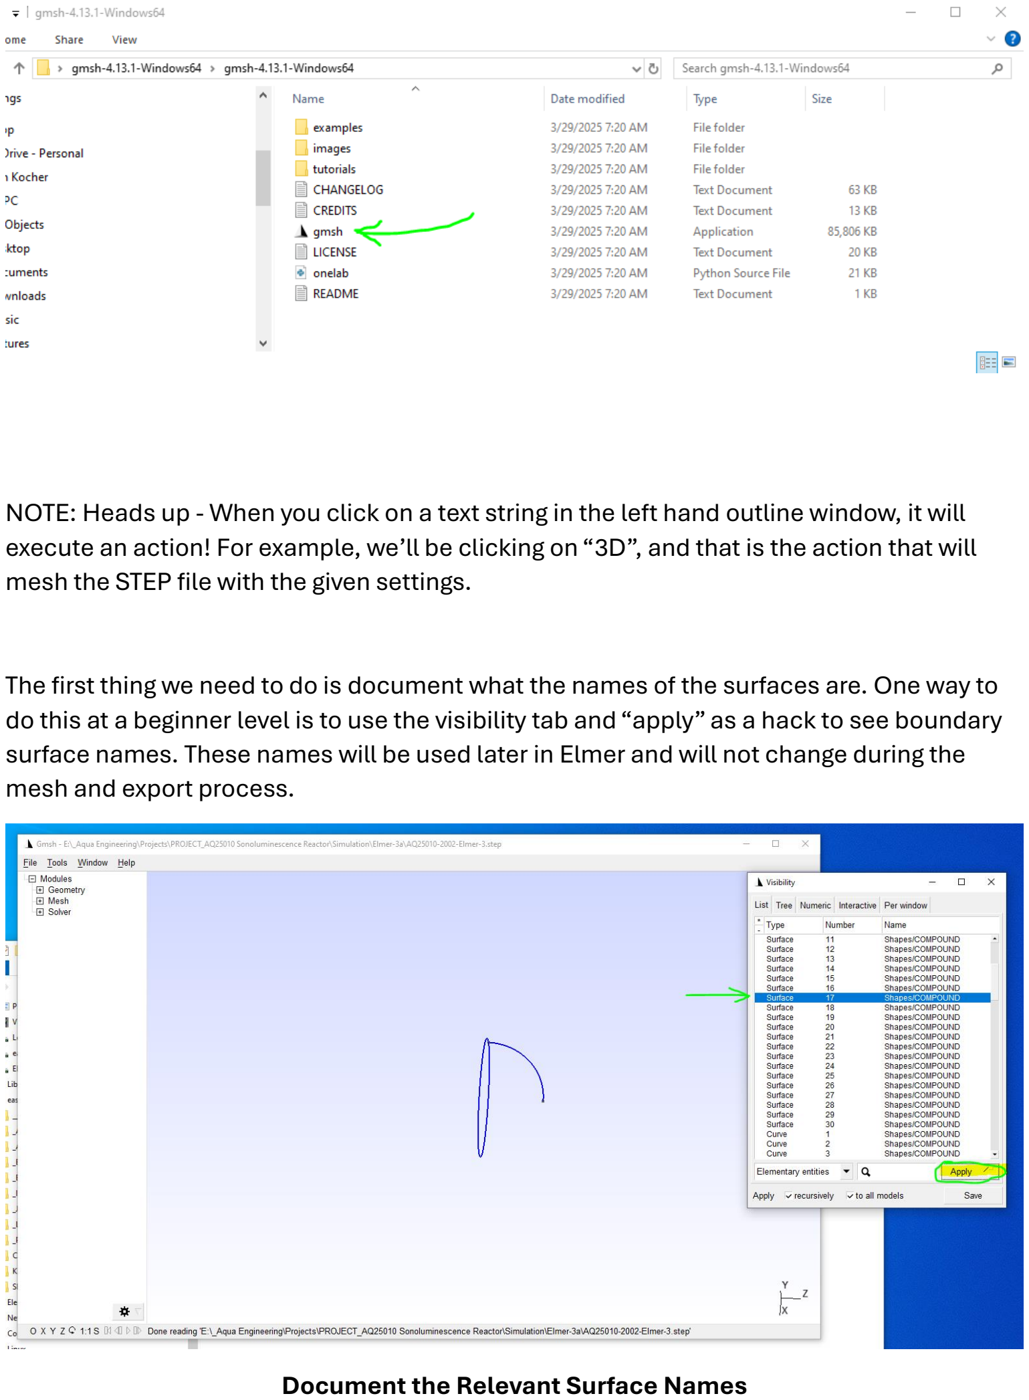
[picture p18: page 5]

NOTE: Heads up - When you click on a text string in the left hand outline window, it will execute an action! For example, we’ll be clicking on “3D”, and that is the action that will mesh the STEP file with the given settings.

The first thing we need to do is document what the names of the surfaces are. One way to do this at a beginner level is to use the visibility tab and “apply” as a hack to see boundary surface names. These names will be used later in Elmer and will not change during the mesh and export process.

Document the Relevant Surface Names

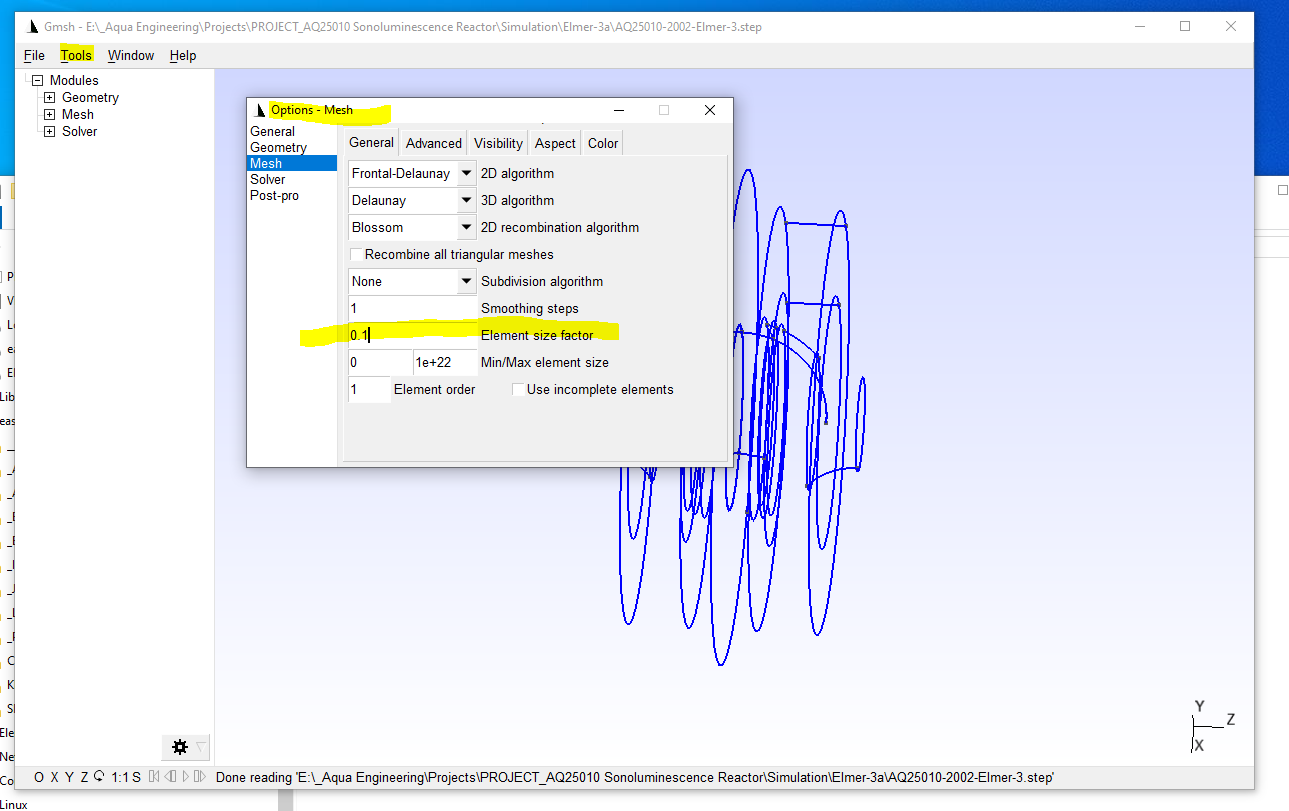
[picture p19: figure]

Set the Mesh Size

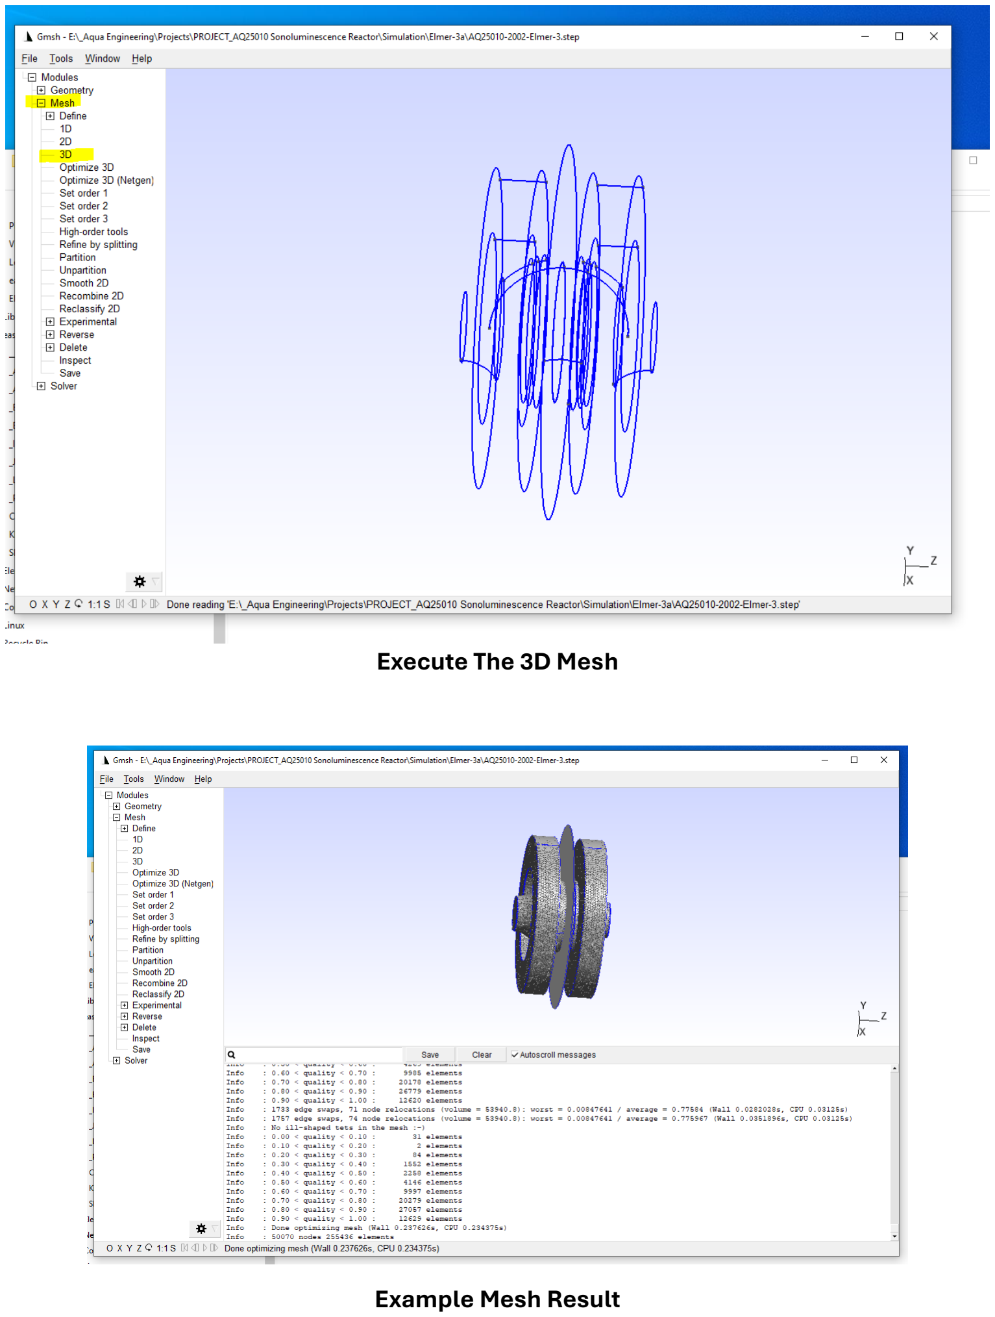
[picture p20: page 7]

Execute The 3D Mesh

Example Mesh Result

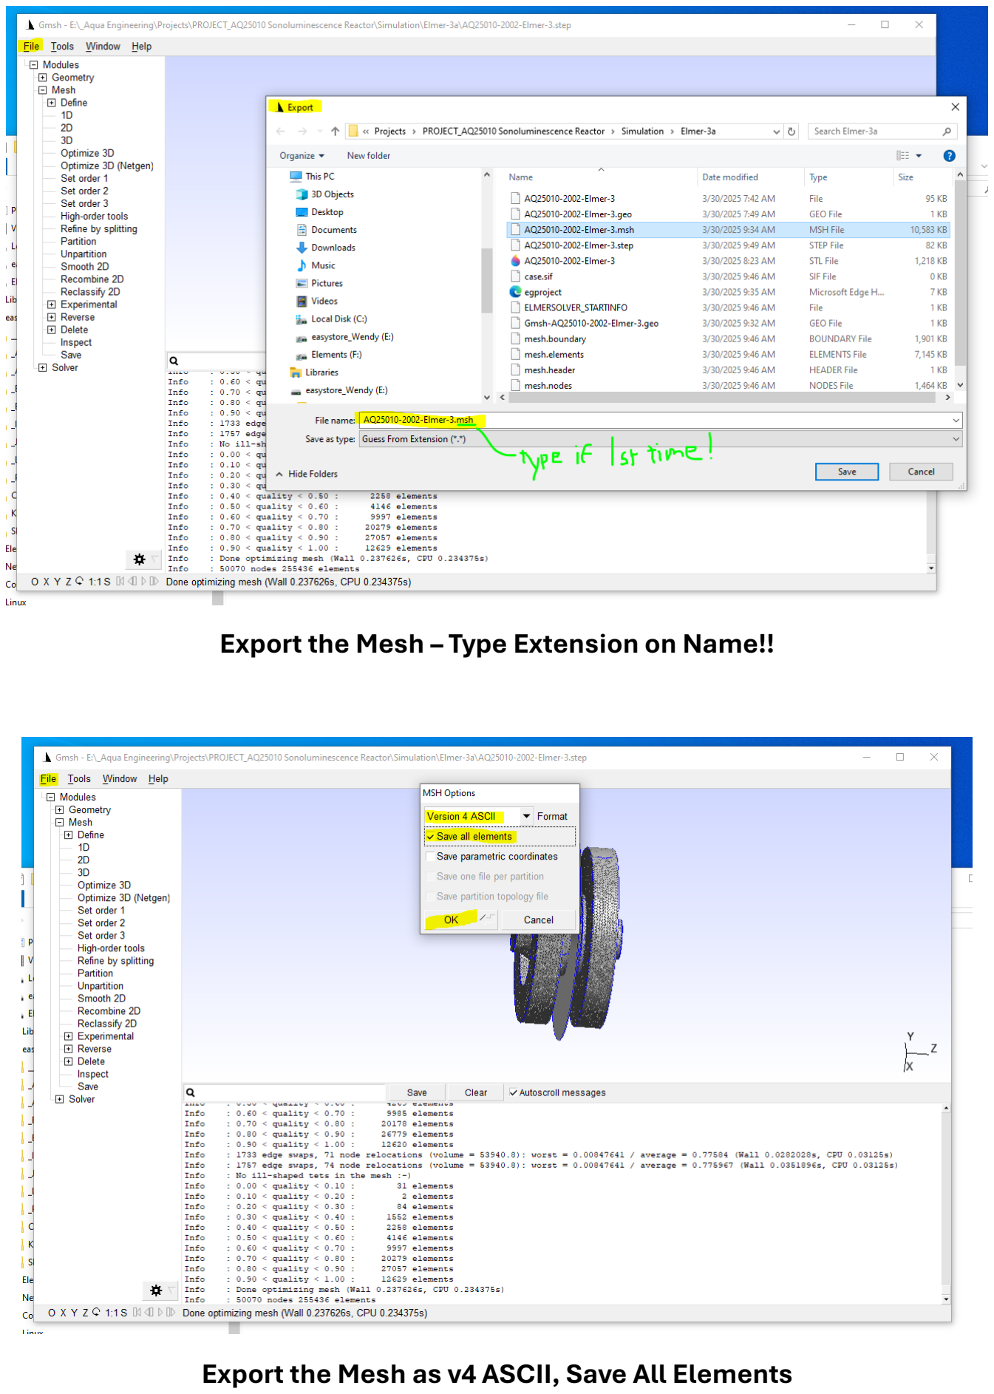
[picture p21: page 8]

Export the Mesh – Type Extension on Name!!

Export the Mesh as v4 ASCII, Save All Elements

## ElmerGUI

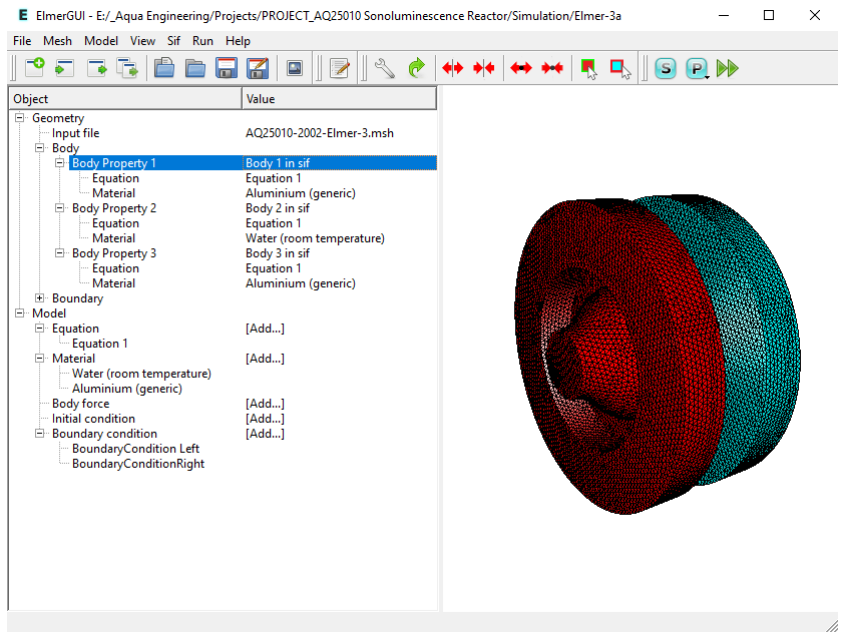
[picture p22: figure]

ElmerGUI is free software we’ll use to run an acoustic Helmholtz FEA simulation. For those unfamiliar with this process, essentially this is a frequency-domain analysis of standing waves that requires no animation or time duration. There will be a bunch of differential equations that require configuration before they can be run. The diff eq’s will have to converge for the simulation to work. Once the basic simulation is successful, details and fine tuning can be iterated. It is suggested that we do not overcomplicate the details on the first pass; or else the process will be infinitely complex. We will configure the simulation for the following main aspects:

## Configure the Elmer Geometry and Model

- Input File (Our .msh file AQ25010-2002-Elmer-3.msh)
- Bodies
- Left Hemisphere
- Bulk Water Volume
- Right Hemisphere
- Equation (in this case it’s the Helmholtz equation)
- Helmholtz Equation
- Active
- Angular Frequency:
- 251327.4 (40 kHz)
- 276991.1 (60 kHz)
- Pick one of these or run others

- Convection
- Convection Velocity 1 = 0.0
- Convection Velocity 2 = 0.0
- Convection Velocity 3 = 0.0
- Apply to Bodies
- Body Property 1
- Body Property 2
- Body Property 3
- Materials:
- Water (room temperature) from library
- Density 998.3
- Heat Capacity: 4183.0
- Heat Expansion Coeff.: 0.207e-3
- Apply to Body Property 2
- Aluminum (generic) from library
- Density: 2700.0
- Heat Capacity: 897.0
- Heat Expansion Coeff.: 23.1e-6
- Apply to Body Property 1
- Apply to Body Property 2
- Boundary conditions:
- Boundary Condition Left
- Flux conditions
- Real Part of the flux: 10000
- Imag part of the flux: 0
- Apply to boundaries:
- Boundary 2 (Change for your specific case)
- Boundary Condition Right
- Flux conditions
- Real part of the flux: 10000
- Imag part of the flux:-10000
- Apply to Boundaries:
- Boundary 27

## SIF >> Generate

Run this command to generate the SIF file. This file contains all of the parameters of the simulation and interestingly, can be used by a Python script to sweep values for those who want to experiment at an advanced level. The python program would define a variable for some or all of the values in the SIF, and Elmer would be called from a command line utility. WARNING: There is a quirk in this process, where the “Sound Speed” is not correctly capitalized. You must do this manually every time you create the SIF.

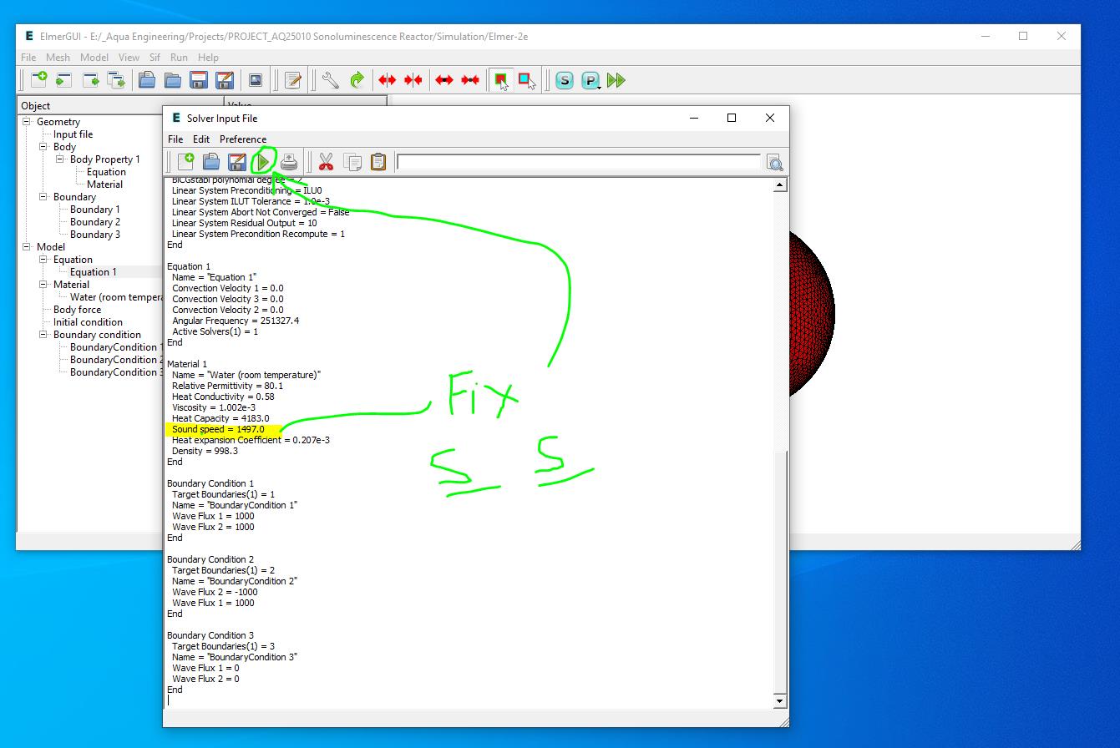
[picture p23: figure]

Fix the SIF, Then Save and Run

## Example SIF file:

Header
CHECK KEYWORDS Warn
Mesh DB "." "."
Include Path ""
Results Directory ""
End

Simulation

Max Output Level = 5
Coordinate System = Cartesian Coordinate Mapping(3) = 1 2 3 Simulation Type = Steady state Steady State Max Iterations = 1 Output Intervals(1) = 1
Solver Input File = case.sif Post File = case.vtu
End

Constants
Gravity(4) = 0 -1 0 9.82
Stefan Boltzmann = 5.670374419e-08 Permittivity of Vacuum = 8.85418781e-12 Permeability of Vacuum = 1.25663706e-6 Boltzmann Constant = 1.380649e-23 Unit Charge = 1.6021766e-19
End

Body 1
Target Bodies(1) = 1
Name = "Body Property 1"
Equation = 1
Material = 2
End

Body 2
Target Bodies(1) = 2
Name = "Body Property 2"
Equation = 1
Material = 1
End

Body 3
Target Bodies(1) = 3
Name = "Body Property 3"
Equation = 1
Material = 2
End

Solver 1

Equation = Helmholtz Equation
Procedure = "HelmholtzSolve" "HelmholtzSolver" Variable = -dofs 2 Pressure Wave
Exec Solver = Always
Stabilize = True
Optimize Bandwidth = True
Steady State Convergence Tolerance = 1.0e-5 Nonlinear System Convergence Tolerance = 1.0e-7 Nonlinear System Max Iterations = 20
Nonlinear System Newton After Iterations = 3 Nonlinear System Newton After Tolerance = 1.0e-3 Nonlinear System Relaxation Factor = 1
Linear System Solver = Iterative
Linear System Iterative Method = BiCGStab Linear System Max Iterations = 500
Linear System Convergence Tolerance = 1.0e-10 BiCGstabl polynomial degree = 2
Linear System Preconditioning = ILU0
Linear System ILUT Tolerance = 1.0e-3
Linear System Abort Not Converged = False Linear System Residual Output = 10 Linear System Precondition Recompute = 1 End

Equation 1
Name = "Equation 1"
Angular Frequency = 251327.4 Convection Velocity 2 = 0.0 Convection Velocity 3 = 0.0 Convection Velocity 1 = 0.0 Active Solvers(1) = 1
End

Material 1
Name = "Water (room temperature)" Relative Permittivity = 80.1
Heat expansion Coefficient = 0.207e-3 Heat Conductivity = 0.58
Viscosity = 1.002e-3
Sound damping = 0.01
Heat Capacity = 4183.0

Density = 998.3
Sound Speed = 1497.0
End

Material 2
Name = "Aluminium (generic)" Poisson ratio = 0.35
Density = 2700.0
Heat expansion Coefficient = 23.1e-6 Heat Capacity = 897.0
Youngs modulus = 70.0e9
Sound Speed = 5000.0
Heat Conductivity = 237.0
End

Boundary Condition 1
Target Boundaries(1) = 2
Name = "BoundaryCondition Left" Wave Flux 2 = 0
Wave Flux 1 = 10000
End

Boundary Condition 4
Target Boundaries(1) = 27
Name = "BoundaryConditionRight" Wave Flux 2 = -10000
Wave Flux 1 = 10000
End

## ParaView

Once we have run the SIF and our Helmholtz FEA has converged successfully, there will be an output file created with a .vtu extension. We need to open this with ParaView and configure a bunch of stuff to visualize the waveform.
WARNING: This process is a game of finding correct orders of magnitude and a using a careful workflow in the Pipeline Browser. Most of our focus is on combining the real and imaginary waveforms “pressure wave 1” and “pressure wave 2” into “result” and being extra careful not to get lost in a cycle of auto rescaling that wipes out our images. As such, it is strongly recommended to SAVE STATE (file >> save state) every time a change is made. This way, as you find your wave images, you can build on progress and avoid an endless cycle of searching for the proper data window.

## Open the .vtu File in ParaView

Navigate to your simulation directory and open the .vtu file with ParaView.

## Add a Calculator Filter

Add a calculator filter to the case_t0001.vtu. You must click on this line in the Pipeline Browser.
WARNING: ParaView treats these Pipeline Browser entries as pipelines, meaning stuff is downstream from other stuff and dependent on upstream entries! This may seem obvious after you use it a few times.
Add the calculator to recover the magnitude waveform from the real and imaginary waveforms.
Filters >> Common >> Calculator
Equation: sqrt("pressure wave 1"^2 + "pressure wave 2"^2)

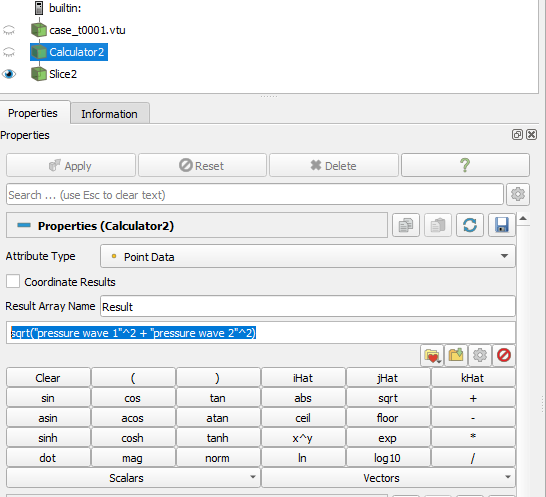
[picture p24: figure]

## Add a Slice Filter

Add a slice filter so you can visualize a section of the standing waveform across both hemispheres and the center region.
Filters >> Common >> Slice

Set the Slice Orientation

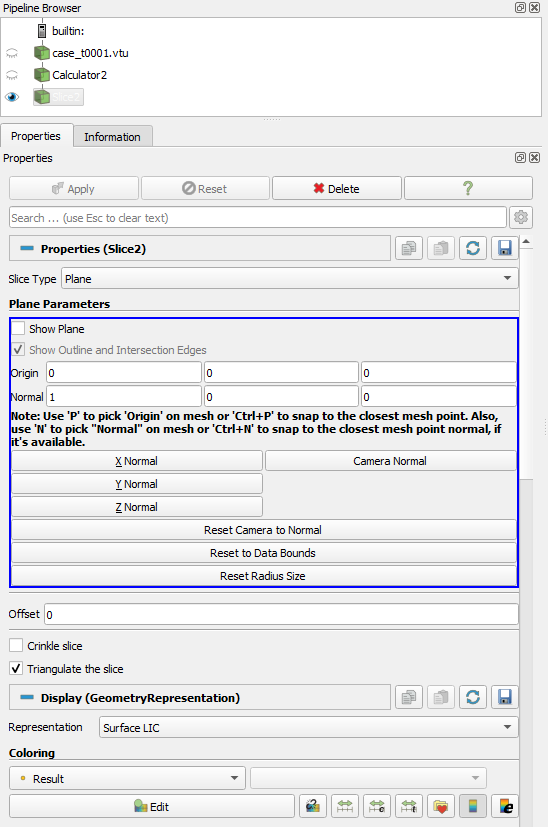
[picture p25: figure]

Set the Colorization Data Range
This is where you might spend most of your time testing, iterating, analyzing, and adjusting so you can interpret the waveform. Fine color details can be easily lost in a range that’s an order of magnitude off and the resulting images saturated beyond value.

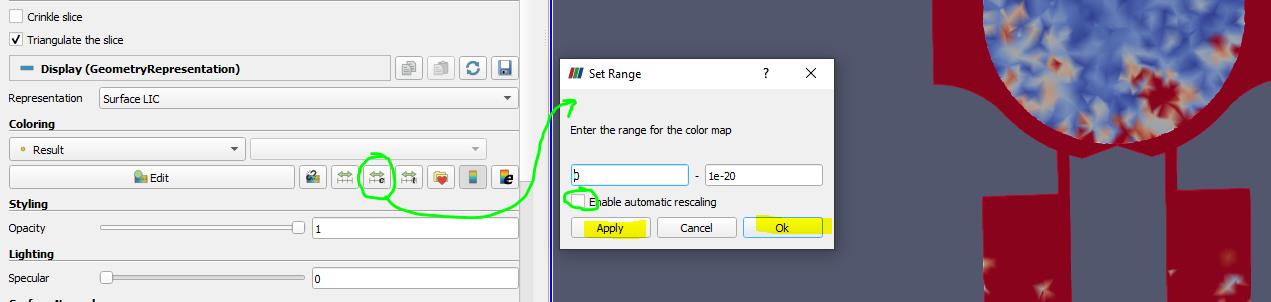
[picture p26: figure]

Reload Files Regularly
Pipeline Browser>>.vtu file>>Right Click>>Reload Files

## Iteration Loop between Elmer and ParaView

As of this writing, Elmer was unable to directly open ParaView, even though the option exists in Elmer. So we’ll manually open and update the vtu file in ParaView every time we run a new simulation.

Here is the general workflow to iterate the simulation quickly:
- Set values and configuration in Elmer
- Elmer>>SIF>>Generate>> Edit Sound Speed for correct case>> Save and Run
- Pipeline Browser>> Right click on the .vtu file>>Reload Files
- Pipeline Browser>>Slice2>>Coloring>>Rescale to Custom Range>>Adjust manually
- Screen shot and save your image with a name that makes sense
- File>>Save State>>Rename as needed to save critical data ranges and colorizations you wish to reproduce later when you adjust the Helmholtz values. This ensures you don’t chase your tail on a fresh auto-scaled data-desert.

## Example Images

The following images are examples from these settings for reference.

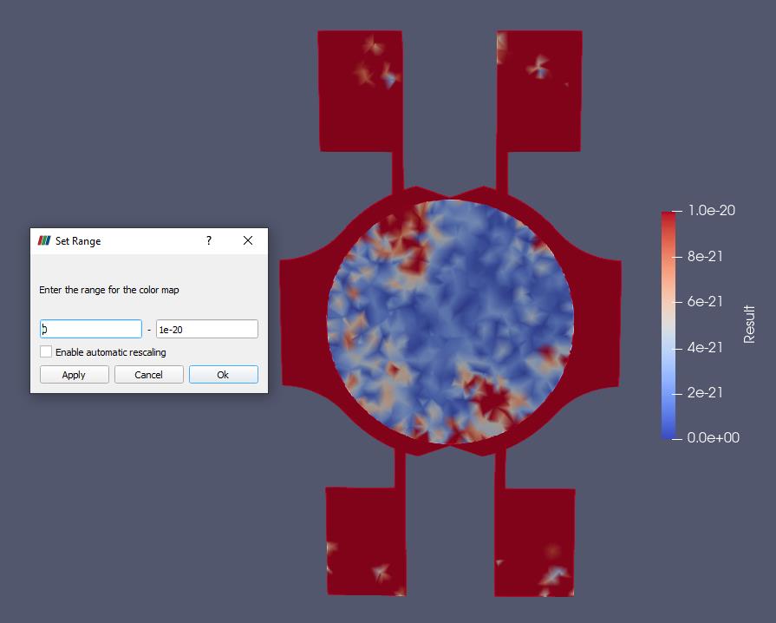
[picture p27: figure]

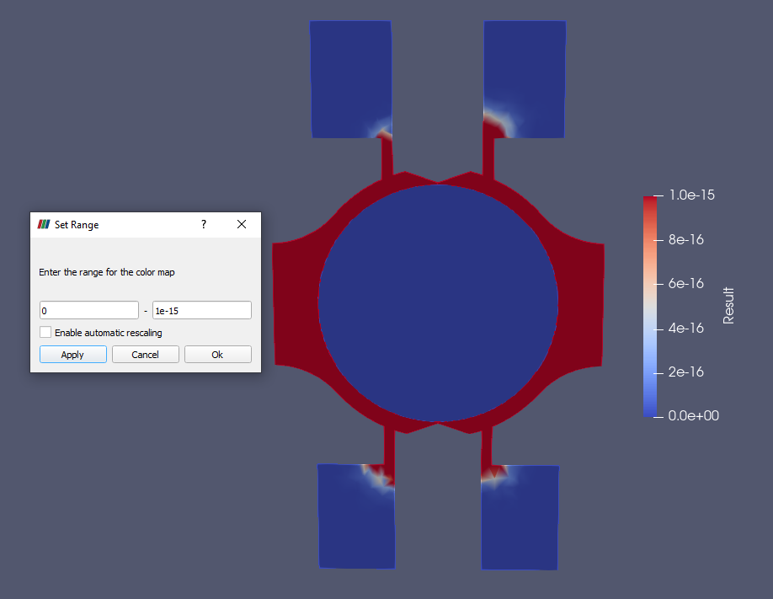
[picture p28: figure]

## Issues and Gotchas Summary

The following were the most painful beginner issues and gotchas:
- 3D model not having a solid volume with split plane regions going into the mesh step
- Gmsh – saving the mesh requires typing the .msh extension the first time, even though there’s a dropdown showing that it will be (should be) in .msh format.
- Elmer – avoid directly driving the wrong surfaces in boundary conditions (BCs). Original pitfall was to assign left drive surface 2 BC (left piezo), surface 14 BC (bulk water sphere), and surface 27 BC (right piezo). This would inject direct energy into the water sphere when what we need is energy transmitted from the left and right aluminum bulkhead horns via their driving surfaces (the flats on each side). It was easier to get a waveform by doing this incorrectly, but it’s not a real life scenario.
- ParaView – Finding a valid data range in a vast sea of orders of magnitude was challenging. A good workflow is to adjust the Coloring>>Set Range fields manually, without automatic rescaling, to avoid chasing your tail when doing tight iteration.

## License:

This license applies to all files in this project, including 3D models, 2D CAD drawings, engineering documentation, source code, and any other associated files, unless otherwise noted.

MIT License

Copyright (c) 2025 Jason Kocher, Aqua Engineering, LLC

Permission is hereby granted, free of charge, to any person obtaining a copy of this software and associated documentation files (the "Software"), to deal in the Software without restriction, including without limitation the rights to use, copy, modify, merge, publish, distribute, sublicense, and/or sell copies of the Software, and to permit persons to whom the Software is furnished to do so, subject to the following conditions:

The above copyright notice and this permission notice shall be included in all copies or substantial portions of the Software.

THE SOFTWARE IS PROVIDED "AS IS", WITHOUT WARRANTY OF ANY KIND, EXPRESS OR IMPLIED, INCLUDING BUT NOT LIMITED TO THE WARRANTIES OF MERCHANTABILITY, FITNESS FOR A PARTICULAR PURPOSE AND NONINFRINGEMENT. IN NO EVENT SHALL THE AUTHORS OR COPYRIGHT HOLDERS BE LIABLE FOR ANY CLAIM, DAMAGES OR OTHER LIABILITY, WHETHER IN AN ACTION OF CONTRACT, TORT OR OTHERWISE, ARISING FROM, OUT OF OR IN CONNECTION WITH THE SOFTWARE OR THE USE OR OTHER DEALINGS IN THE SOFTWARE.

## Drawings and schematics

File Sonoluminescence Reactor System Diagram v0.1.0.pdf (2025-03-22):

# Sonoluminescence Reactor v0.1.0

# PRELIMINARY

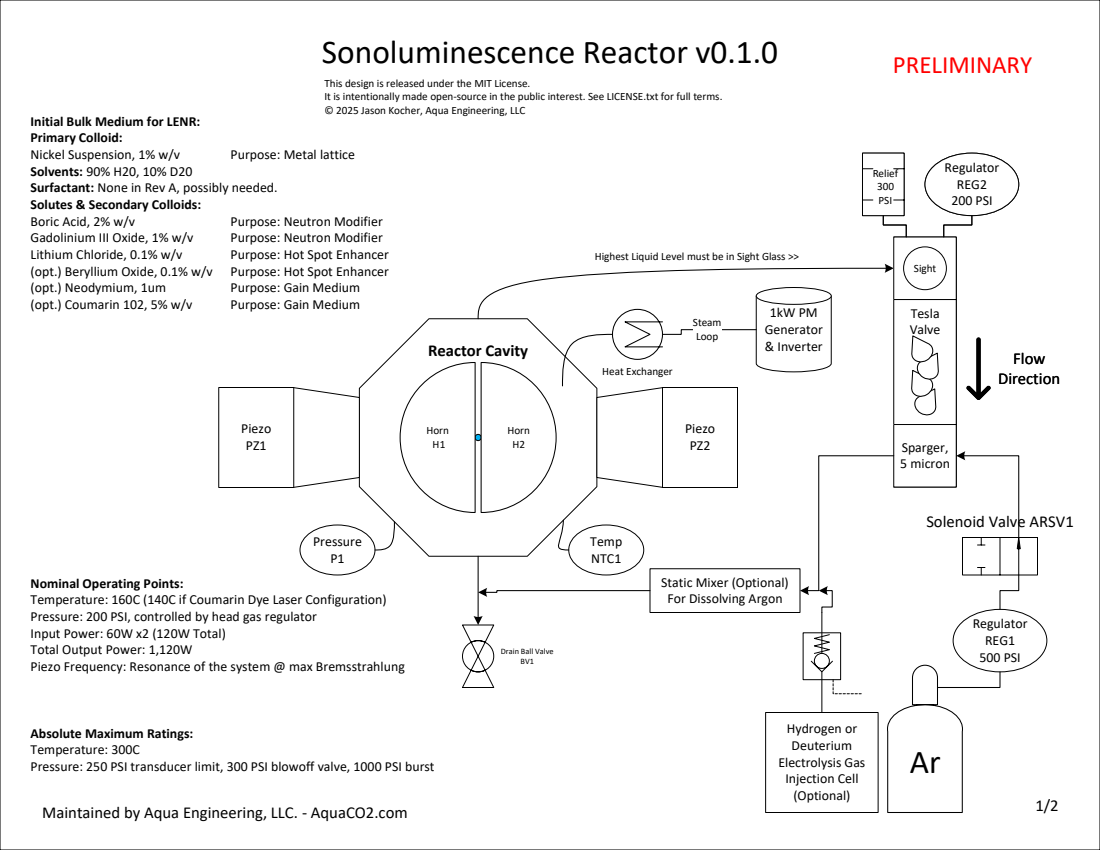
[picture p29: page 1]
Reactor Cavity; Horn H1; Horn H2; Piezo PZ2; Piezo PZ1; Heat Exchanger; Solenoid Valve ARSV1; Regulator REG1 500 PSI; 1kW PM Generator & Inverter; Steam Loop; Tesla Valve; Sparger, 5 micron; Sight; Relief 300 PSI; Regulator REG2 200 PSI; Nickel Suspension, 1% w/v; Purpose: Metal lattice; Boric Acid, 2% w/v; Purpose: Neutron Modifier; Gadolinium III Oxide, 1% w/v; Lithium Chloride, 0.1% w/v; Purpose: Hot Spot Enhancer; (opt.) Beryllium Oxide, 0.1% w/v; (opt.) Neodymium, 1um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

This design is released under the MIT License.
It is intentionally made open-source in the public interest. See LICENSE.txt for full terms.
© 2025 Jason Kocher, Aqua Engineering, LLC

Initial Bulk Medium for LENR:
Primary Colloid:
Solvents: 90% H20, 10% D20
Surfactant: None in Rev A, possibly needed.
Solutes & Secondary Colloids:

Highest Liquid Level must be in Sight Glass >>

Nominal Operating Points:
Temperature: 160C (140C if Coumarin Dye Laser Configuration)
Pressure: 200 PSI, controlled by head gas regulator
Input Power: 60W x2 (120W Total)
Total Output Power: 1,120W
Piezo Frequency: Resonance of the system @ max Bremsstrahlung

Static Mixer (Optional)
For Dissolving Argon

Drain Ball Valve

Absolute Maximum Ratings:
Temperature: 300C
Pressure: 250 PSI transducer limit, 300 PSI blowoff valve, 1000 PSI burst

Sonoluminescence Reactor v0.1.0 | PRELIMINARY

# Viewing Port

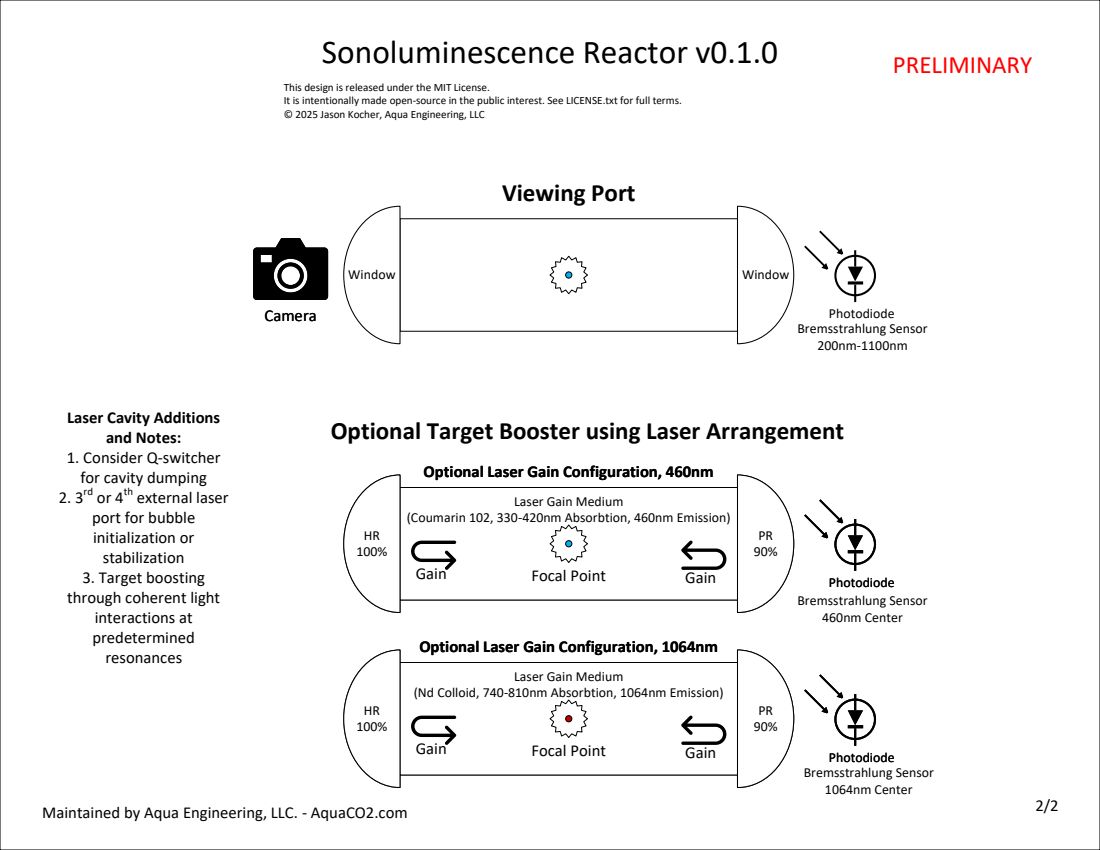
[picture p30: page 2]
Gain; Focal Point; Photodiode; Window; Bremsstrahlung Sensor 200nm-1100nm; Camera; Bremsstrahlung Sensor 460nm Center; Bremsstrahlung Sensor 1064nm Center

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

Optional Target Booster using Laser Arrangement Laser Cavity Additions
and Notes:
1. Consider Q-switcher
for cavity dumping
2. 3rd or 4th external laser
port for bubble
initialization or
stabilization
3. Target boosting
through coherent light
interactions at
predetermined
resonances

Optional Laser Gain Configuration, 460nm

Laser Gain Medium

(Coumarin 102, 330-420nm Absorbtion, 460nm Emission)

Optional Laser Gain Configuration, 1064nm

(Nd Colloid, 740-810nm Absorbtion, 1064nm Emission)

Maintained by Aqua Engineering, LLC. - AquaCO2.com

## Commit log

2025-03-31 Added FEA simulation files and instructions
    [AQ25010-2002-Elmer-3.step, AQ25010-2002-Elmer-3.stl]
2026-03-06 feat(elmer): add automated frequency sweep script
    Automates the manual process of editing Angular Frequency in case.sif,
    running ElmerSolver, and collecting results — as envisioned in the
    Simulation Guide (page 11).
    - Auto-detects ElmerSolver via PATH or ELMER_SOLVER env var
    - Safely restores case.sif after sweep, even on Ctrl+C
    - Writes CSV summary for downstream analysis
    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
2026-03-07 feat(analysis): add sweep post-processor and cavity mode tools
    sweep_analysis.py reads VTU files from frequency sweeps, computes
    pressure amplitude diagnostics (max, mean, center), and generates
    frequency response plots, axial profiles, and enriched CSV output.
    cavity_modes.py provides analytical resonance predictions using
    spherical Bessel functions, including reverse design (target freq
    to optimal radius) and cavity design charts.
    docs/acoustic-analysis.md documents findings from validating these
    tools against the existing simulation, including unit-consistency
    observations and before/after comparisons with corrected results.
